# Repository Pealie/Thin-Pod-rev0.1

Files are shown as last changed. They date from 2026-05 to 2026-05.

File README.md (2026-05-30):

# Thin-Pod rev 0.1

<p align="left">
  <a href="https://certification.oshwa.org/uk000091.html">
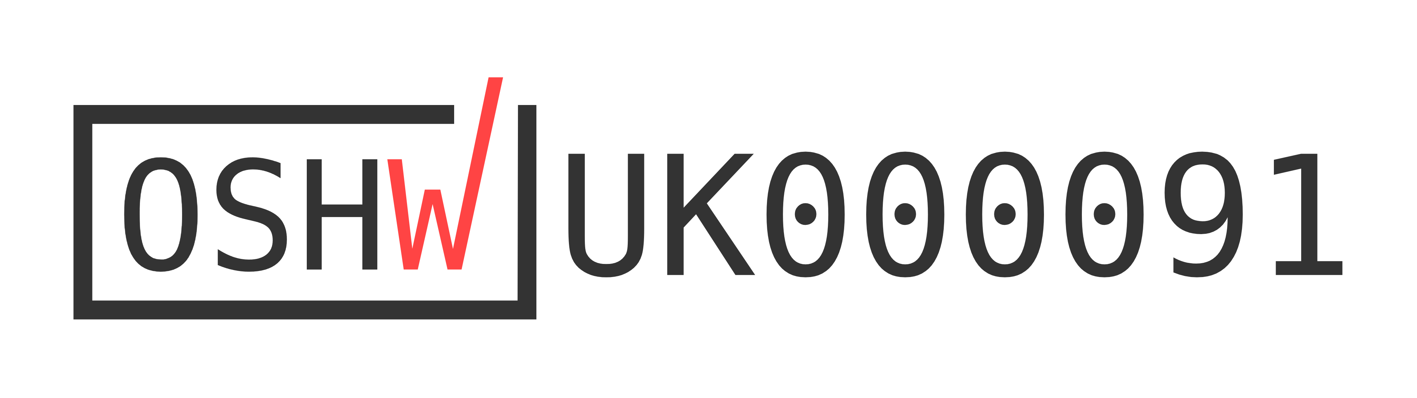
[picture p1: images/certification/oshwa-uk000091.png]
Open Source Hardware Association certification mark: UK000091
    
  </a>
</p>
<p align="left">
  <strong>OSHWA Certified Open Source Hardware · UK000091</strong><br>
  Certified 28 May 2026 · <a href="https://certification.oshwa.org/uk000091.html">View certification record</a>
</p>

## Overview

Thin-Pod rev 0.1 is a compact analogue vibration-sensing carrier board intended for experimental condition-monitoring work on motors, pumps, fans, gearboxes and similar rotating machinery. The board supports an ADXL1005-based analogue accelerometer signal path and provides protected power entry, a regulated and switched sensor supply, signal conditioning, accessible test points and a mating interface for a commercially supplied Qorvo DWM3001-CDK development board.

The design is published as an open-hardware PCB release: editable KiCad source files, project-local library files, fabrication outputs, bill of materials and verification documentation are provided in this repository.

The release is intentionally bounded: its value lies in producing a reproducible, inspectable measurement endpoint whose power path, signal path, interface assumptions and validation evidence can support later Gateway-side analysis, reporting and evaluation work within a clearly defined certified hardware boundary.

## Certification scope

The OSHWA certification for **Thin-Pod rev 0.1** covers the creator-designed sensor-node carrier PCB and its release documentation.

### Included in scope

* Two-layer Thin-Pod carrier PCB design.
* Protected power-entry path, fuse provision and reverse-polarity protection.
* Regulated 3.3 V power path and PFET-switched accelerometer supply.
* ADXL1005 analogue sensor interface and conditioned signal path.
* Electrical test points for bring-up and measurement.
* Thin-Pod-authored mating interface for a Qorvo DWM3001-CDK.
* Corrected carrier-board ground return for the DWM3001-CDK interface.
* Editable KiCad source files, fabrication outputs, BOM and documentation.

### Outside scope

* The Qorvo DWM3001-CDK itself as open hardware.
* The Analog Devices ADXL1005 device or any vendor evaluation board as open hardware.
* The Pololu S7V8F3 regulator module as open hardware.
* The separately developed Thin-Pod Gateway.
* STM32 NUCLEO-N657X0-Q, ESP32-C6 or Gateway-side hardware.
* Implemented UWB communication, radio firmware or networking.
* Gateway-side DSP, TinyML inference, anomaly detection or predictive-maintenance classification.
* AI-assisted maintenance reporting, structured evidence-bound reports or autonomous maintenance decisions.

The commercial devices used by the board are identified as third-party components; they are not relicensed or represented as creator-designed open hardware.

## System role and infrastructure context

Thin-Pod rev 0.1 is the sensing-node hardware layer within a broader experimental condition-monitoring architecture. Its immediate role is to provide a reproducible, inspectable and electrically verified vibration-measurement endpoint for motors, pumps, fans, gearboxes and similar rotating machinery.

```
Machine / motor / pump
        ↓
Thin-Pod rev 0.1 sensing node
        ↓
ADC / UWB-capable commercial module interface
        ↓
Gateway transport and analysis layer
        ↓
Maintenance telemetry / diagnostic workflow
```

The infrastructure concerns addressed by this release are measurement integrity, power-path robustness, interface definition, third-party component boundaries, traceable validation evidence and manufacturable open-hardware documentation.

Only the Thin-Pod rev 0.1 sensing-node carrier PCB and its release documentation are included in the certified open-hardware scope. The ADC-capable commercial module interface is documented as part of the board design, but the commercial module itself is not claimed as open hardware.

Gateway transport, UWB communications, networking, DSP, TinyML, anomaly detection and maintenance-diagnostic workflows are shown here to clarify the intended system context. They are part of the wider Thin-Pod development direction, but remain outside the certified rev 0.1 hardware release.

This boundary is deliberate. Thin-Pod rev 0.1 is designed to make the physical measurement layer explicit before higher-level interpretation is attempted. Later Gateway or software layers can consume the resulting signal path, but any DSP, anomaly detection, AI-assisted reporting or maintenance recommendation must remain separately implemented, evaluated and documented.

## Functional architecture

```text
Mechanical vibration
        ↓
ADXL1005 analogue accelerometer interface
        ↓
Analogue conditioning / filtered signal node
        ↓
Accessible test point and CDK ADC interface
        ↓
Commercial Qorvo DWM3001-CDK connection
```

Power is arranged as:

```text
RAW_IN → fuse provision → 1N5817 reverse-polarity protection
       → Pololu S7V8F3 regulated 3.3 V rail
       → PFET-switched accelerometer supply
```

## Evidence-chain design intent

Thin-Pod rev 0.1 is intended to support an evidence-chain approach to experimental condition monitoring. The carrier board provides the physical sensing and interface layer; later Gateway-side work may attach acquisition metadata, operating-context records, DSP feature outputs, baseline comparisons and report provenance.

In that wider architecture, the hardware layer should remain distinct from any interpretive software layer. The board records or exposes a vibration signal; it does not itself diagnose machine faults. This separation is important for reproducibility, safety, evaluation and possible future AI-assisted reporting workflows.

## DWM3001-CDK ground-return correction

During bring-up of an earlier pre-release manufactured prototype, the CDK did not establish the assumed functional ground return through the original power-entry arrangement alone. A temporary ground jumper allowed successful electrical bring-up and measurement of the sensor path.

Before freezing the rev 0.1 open-hardware release, the CDK mating interface and carrier-board connection were corrected so that all relevant CDK ground connections resolve directly to the Thin-Pod `GND` net:

```text
J1_2    GND    ─┐
J1_6    GND_1  ─┤
J10_9   GND_2  ─┤
J10_14  GND_3  ─┼── GND
J10_20  GND_4  ─┤
J10_25  GND_5  ─┘
```

The editable source and fabrication outputs in this repository include that correction. The temporary jumper is part of the prototype history and is **not** an assembly requirement for the released rev 0.1 design.

## Validation status

The first manufactured pre-release prototype established that the core sensor-node approach is electrically viable. Measurements made during prototype bring-up included:

|Validation item|Result|Evidence status|
|-|-|-|
|Manufactured PCB inspection and initial assembly|Completed|Documented in bring-up record and images|
|Power-up after temporary CDK ground-return correction|Successful|Documented prototype result|
|Switched accelerometer supply rail|Approximately 3.35 V measured|Documented prototype result|
|Filtered analogue sensor output|Approximately 1.76 V measured at rest|Documented prototype result|
|Mechanical excitation / tap response|Visible on oscilloscope|Documented prototype result|
|Ground-return correction implemented in released KiCad source and Gerbers|Completed|Included in this release|
|Physical re-test of the corrected copper implementation without jumper|To be recorded after manufacture of the corrected release board|Not claimed as completed|

The prototype measurement evidence supports the power and analogue signal-chain design. The corrected ground-return implementation is present in the released design files; it is not represented as physically re-tested until a board manufactured from these release Gerbers has been assembled and measured.

## Repository contents

```text
Thin-Pod-rev0.1/
├── README.md
├── LICENCE-HARDWARE.md
├── LICENCE-DOCUMENTATION.md
│
├── hardware/
│   ├── source/
│   │   ├── Thin-Pod_rev0.1.kicad_pro
│   │   ├── Thin-Pod_rev0.1.kicad_sch
│   │   ├── Thin-Pod_rev0.1.kicad_pcb
│   │   ├── fp-lib-table
│   │   ├── sym-lib-table
│   │   ├── footprints/
│   │   │   └── ThinPod.pretty/
│   │   │       └── ThinPod_DWM3001CDK_Mating_Interface_revA.kicad_mod
│   │   └── symbols/
│   │       └── ThinPod.kicad_sym
│   │
│   ├── fabrication/
│   │   ├── gerbers/
│   │   ├── drills/
│   │   └── Thin-Pod_rev0.1_fabrication_outputs.zip
│   │
│   └── bom/
│       ├── Thin-Pod_rev0.1_BOM.md
│       └── Thin-Pod_rev0.1_BOM.csv
│
├── docs/
│   ├── certification-scope.md
│   ├── third-party-components.md
│   ├── footprint-provenance.md
│   ├── prototype-bring-up-and-release-correction.md
│   ├── design-verification.md
│   └── future-revisions.md
│
├── images/
│   ├── certification/
│   │   └── oshwa-uk000091.png
│   ├── prototype-bring-up/
│   ├── gerber-inspection/
│   └── released-design/
│	└── README.md
│
└── oshwa/
    └── application-record.md
    └── README.md
```

## Design and fabrication files

|Resource|Location|Purpose|
|-|-|-|
|Editable KiCad project, schematic and PCB|[`hardware/source/`](hardware/source/)|Preferred source for modification|
|Project-local footprints and symbols|[`hardware/source/`](hardware/source/)|Portable project dependencies|
|Gerber and drill files|[`hardware/fabrication/`](hardware/fabrication/)|PCB fabrication outputs|
|Bill of materials|[`hardware/bom/`](hardware/bom/)|Assembly and sourcing record|
|Certification and design documentation|[`docs/`](docs/)|Scope, provenance and validation record|
|OSHWA application and certification record|[`oshwa/application-record.md`](oshwa/application-record.md)|Public submission details and certification UID|

The editable KiCad source files are the normative design source. Gerbers and drill files are derived fabrication outputs supplied for convenience and reproducibility.

## Bill of materials

The release BOM covers the Thin-Pod rev 0.1 sensor-node carrier board only. It identifies the fitted PCB components, commercial subassemblies, component values, footprints and sourcing information required to reproduce this release.

The Gateway, Gateway-side radio components, ESP32 networking hardware and analytic processing hardware are not part of this BOM because they are outside the rev 0.1 certification scope.

See:

* [`hardware/bom/Thin-Pod_rev0.1_BOM.md`](hardware/bom/Thin-Pod_rev0.1_BOM.md)
* [`hardware/bom/Thin-Pod_rev0.1_BOM.csv`](hardware/bom/Thin-Pod_rev0.1_BOM.csv)

## Third-party components

Thin-Pod rev 0.1 is an open carrier-board design built around commercially available components. The following items are used or interfaced by the design but are not claimed as open-hardware contributions of this project:

|Component|Function in Thin-Pod rev 0.1|Treatment in this release|
|-|-|-|
|Analog Devices ADXL1005-based accelerometer implementation|Analogue vibration sensing|Commercial third-party component; interface documented|
|Qorvo DWM3001-CDK|Commercial module connected through the pod-side mating interface|Commercial third-party development board; not relicensed|
|Pololu S7V8F3|Regulated 3.3 V supply module|Commercial third-party module|
|ZVP2106A and standard passive/protection components|Power switching and analogue support circuitry|Commercial bought-in components identified in BOM|

Vendor documentation is referenced for sourcing and interface understanding; vendor CAD files, proprietary board layouts and vendor 3D models are not distributed under the Thin-Pod hardware licence.

## CDK mating-interface footprint provenance

The published footprint:

```text
hardware/source/footprints/ThinPod.pretty/
└── ThinPod_DWM3001CDK_Mating_Interface_revA.kicad_mod
```

is a Thin-Pod project-local mating-interface footprint for the commercially supplied DWM3001-CDK. It is intended to describe only the mechanical and electrical connection required by the Thin-Pod carrier PCB.

The release footprint was independently constructed in KiCad using standard connector geometry, publicly available interface information and mechanical verification against a purchased CDK unit. It does not distribute a Qorvo-supplied CAD footprint, CDK PCB design or vendor 3D model.

## Opening and modifying the design

The source design is maintained in KiCad 10.0.1. The project is intended to be portable through project-local symbol and footprint tables.

A reproducible modification workflow is:

1. Open `hardware/source/Thin-Pod_rev0.1.kicad_pro` in KiCad 10.0.1 or a compatible later version.
2. Confirm that project-local symbol and footprint libraries resolve through `sym-lib-table` and `fp-lib-table`.
3. Run schematic ERC and PCB DRC before fabrication.
4. Regenerate Gerber and drill outputs after any accepted design change.
5. Inspect copper, solder mask, silkscreen, board outline and drill alignment in KiCad Gerber Viewer before ordering.

## Documentation and verification record

|Document|Content|
|-|-|
|[`docs/certification-scope.md`](docs/certification-scope.md)|Formal inclusion and exclusion boundary for certification|
|[`docs/third-party-components.md`](docs/third-party-components.md)|Commercial component and vendor-material notice|
|[`docs/footprint-provenance.md`](docs/footprint-provenance.md)|Origin and verification of the CDK mating-interface footprint|
|[`docs/prototype-bring-up-and-release-correction.md`](docs/prototype-bring-up-and-release-correction.md)|Prototype test result and ground-return design correction|
|[`docs/design-verification.md`](docs/design-verification.md)|Electrical and fabrication verification record|
|[`docs/future-revisions.md`](docs/future-revisions.md)|Items explicitly outside this release|

## Licensing

|Material|Licence|File|
|-|-|-|
|Creator-designed hardware source, including schematics, PCB layout and Thin-Pod-authored footprint files|CERN Open Hardware Licence Version 2 — Weakly Reciprocal (`CERN-OHL-W-2.0`)|[`LICENCE-HARDWARE.md`](LICENCE-HARDWARE.md)|
|Creator-authored documentation, diagrams and photographs|Creative Commons Attribution 4.0 International (`CC-BY-4.0`)|[`LICENCE-DOCUMENTATION.md`](LICENCE-DOCUMENTATION.md)|
|Software / firmware|None required or supplied for the certified rev 0.1 hardware scope|Not applicable|

Commercial components, vendor documentation and any third-party intellectual property remain subject to their respective owners' terms and are not covered by the Thin-Pod licences. The OSHWA certification mark is used to identify this certified release and is not relicensed as Thin-Pod documentation.

## OSHWA certification record

**Thin-Pod rev 0.1 is certified open source hardware under OSHWA UID UK000091.** The certification mark displayed near the top of this README identifies this specific certified release and links to the public OSHWA record.

|Field|Value|
|-|-|
|Project name|Thin-Pod|
|Project version|0.1|
|Primary project type|Electronics|
|Certification scope|Vibration-sensor node carrier PCB|
|Certification date|28 May 2026|
|Hardware licence|CERN-OHL-W-2.0|
|Documentation licence|CC-BY-4.0|
|Software licence|No software required or supplied for the certified hardware scope|
|OSHWA UID|UK000091|
|Official record|[certification.oshwa.org/uk000091](https://certification.oshwa.org/uk000091.html)|

The certification UID and matching mark are retained in this README and in [`oshwa/application-record.md`](oshwa/application-record.md), keeping the boundary of the certified rev 0.1 release explicit.

## Safety and regulatory note

Thin-Pod rev 0.1 is experimental sensing hardware. It has not been certified for installation on safety-critical machinery, hazardous environments or regulated industrial monitoring applications. Appropriate isolation, current-limited bench testing, secure mechanical mounting and safe working practices are required during evaluation.

This open-hardware release does not imply EMC, radio, electrical-safety or product-regulatory approval. Any commercially supplied radio or development module remains subject to its own vendor documentation and applicable regulatory conditions.

## References

* [Thin-Pod OSHWA Certification Record — UK000091](https://certification.oshwa.org/uk000091.html)
* [OSHWA Certification Mark Usage Guide](https://certification.oshwa.org/mark-usage.html)
* [OSHWA Certification Requirements](https://certification.oshwa.org/requirements.html)
* [OSHWA Certification Documentation Process](https://certification.oshwa.org/process/documentation.html)
* [OSHWA Certification Application](https://application.oshwa.org/apply)
* [Qorvo DWM3001-CDK product page](https://www.qorvo.com/products/p/DWM3001CDK)
* [Analog Devices ADXL1005 product page](https://www.analog.com/en/products/adxl1005.html)

---

**Thin-Pod rev 0.1** is a deliberately bounded first open-hardware release: a documented vibration-sensor node PCB with a clear commercial-module boundary, an independently authored interface footprint, traceable prototype-validation evidence and a release design that incorporates the principal lesson discovered during bring-up.

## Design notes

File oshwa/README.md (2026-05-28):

# OSHWA Certification Record

This directory contains the public certification record for **Thin-Pod rev 0.1**, an open-hardware vibration-sensor node carrier PCB for rotating-machinery experiments.

## Certification status

**Thin-Pod rev 0.1 is OSHWA Certified Open Source Hardware.**

|Field|Value|
|-|-|
|Project|Thin-Pod|
|Hardware release|rev 0.1|
|OSHWA UID|UK000091|
|Certification date|28 May 2026|
|Certified item|Vibration-sensor node carrier PCB|
|Hardware licence|CERN-OHL-W-2.0|
|Documentation licence|CC-BY-4.0|
|Official certification record|[certification.oshwa.org/uk000091](https://certification.oshwa.org/uk000091.html)|

## Contents

|File|Purpose|
|-|-|
|[`application-record.md`](application-record.md)|Public record of the submitted project description, certification boundary, licence declarations, commercial-component treatment, provenance position and verification evidence supporting the certified release.|

## Certified scope

The certification applies to the **Thin-Pod rev 0.1 creator-designed carrier PCB** and its released documentation. The certified hardware scope includes the protected power-entry path, regulated and switched accelerometer supply, ADXL1005-based analogue sensing interface, conditioned signal path, bring-up test points, Thin-Pod-authored DWM3001-CDK mating interface, and the corrected CDK ground-return implementation incorporated in the released design files.

The following remain outside this certification scope:

* commercially supplied components or development boards, including the Qorvo DWM3001-CDK, Analog Devices ADXL1005 device or evaluation hardware, and Pololu S7V8F3 module;
* the separately developed Thin-Pod Gateway;
* implemented UWB communications, radio firmware and networking;
* Gateway DSP, TinyML, anomaly-detection and predictive-maintenance system claims;
* EMC, radio, safety or other regulatory approval.

## Documentation boundary

The open-hardware contribution is the Thin-Pod-created carrier-board design, editable source, fabrication outputs and creator-authored documentation. Bought-in components and third-party CAD dependencies are identified for reproduction and provenance purposes; they are not presented as Thin-Pod-created open hardware or relicensed by this project.

The repository-level description of the certified release is held in [`../README.md`](../README.md). Hardware and documentation licences are provided at:

* [`../LICENCE-HARDWARE.md`](../LICENCE-HARDWARE.md)
* [`../LICENCE-DOCS.md`](../LICENCE-DOCS.md)

## Public-record note

[`application-record.md`](application-record.md) records the public, non-sensitive substance of the OSHWA certification application and subsequent certification milestone. Private postal-address information, private correspondence details and any non-public application data are intentionally excluded.

Any later electrical or mechanical design change should be recorded as a subsequent hardware revision rather than silently replacing the documented **rev 0.1** certified release.

\---

**Thin-Pod rev 0.1 · OSHWA UID UK000091 · Certified 28 May 2026**

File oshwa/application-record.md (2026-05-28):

# Thin-Pod rev 0.1: OSHWA Application Record

**Project:** Thin-Pod  
**Hardware release:** rev 0.1  
**Responsible individual:** Neil Thomson / Pealie  
**Repository:** [Pealie/Thin-Pod-rev0.1](https://github.com/Pealie/Thin-Pod-rev0.1)  
**Application status:** Submitted to the Open Source Hardware Association (OSHWA) certification programme  
**Certification date:** 28 May 2026  
**OSHWA UID:** OSHWA UID UK000091  
**Document status:** Public application record

## 1\. Purpose

This document records the public, non-sensitive substance of the OSHWA certification application submitted for **Thin-Pod rev 0.1**.

The OSHWA application includes private correspondence and address information supplied directly to OSHWA. That information is intentionally not reproduced in this public repository record. This document instead records the certified item, the declared scope, the licensing position, the public documentation location and the supporting design-release evidence.

Once an OSHWA certification UID has been supplied or confirmed in the public certification directory, this document and the repository `README.md` should be updated to include it.

## 2\. Submitted certified item

The item submitted for OSHWA certification is:

> \*\*Thin-Pod rev 0.1: an open-hardware vibration-sensor node carrier PCB for rotating-machinery experiments.\*\*

Thin-Pod rev 0.1 is a creator-designed sensor-node carrier PCB providing protected power entry, regulated and switched sensor power, an ADXL1005-based analogue vibration-sensing interface, signal conditioning, accessible electrical test points and a corrected mating interface for a commercially supplied Qorvo DWM3001-CDK development board.

## 3\. Certification boundary

### Included in the submitted hardware scope

|Included element|Description|
|-|-|
|Thin-Pod rev 0.1 PCB|Two-layer creator-designed sensor-node carrier board|
|Power entry and protection|RAW\_IN connection, fuse provision and 1N5817 reverse-polarity protection|
|Regulated power path|Interface for the specified commercial 3.3 V regulator module|
|Switched sensor supply|PFET-controlled accelerometer supply rail|
|Analogue sensing interface|ADXL1005-based vibration-sensor electrical/mechanical interface|
|Signal conditioning and measurement|Raw/filtered signal path and TP1–TP7 bring-up points|
|CDK carrier interface|Thin-Pod-authored mating-interface footprint and PCB connectivity for the DWM3001-CDK|
|Corrected CDK ground return|Carrier-board ground connection incorporated into the released KiCad source and Gerbers|
|Release source and documentation|Editable KiCad files, fabrication outputs, BOM, provenance record and verification documentation|

### Explicitly outside the submitted scope

|Excluded element|Reason for exclusion|
|-|-|
|Qorvo DWM3001-CDK as open hardware|Commercial third-party development board used by the assembly, not a Thin-Pod-authored product|
|Analog Devices ADXL1005 device or evaluation board as open hardware|Commercial third-party sensing component/module|
|Pololu S7V8F3 module as open hardware|Commercial third-party regulator module|
|Thin-Pod Gateway|Separate evolving hardware artefact|
|STM32 NUCLEO-N657X0-Q and ESP32-C6 Gateway hardware|Outside the sensor-node carrier-board release|
|Implemented UWB communications|No completed wireless-implementation claim was submitted for rev 0.1|
|DSP, TinyML or anomaly detection|Future/system-level processing functionality outside this hardware application|
|Predictive-maintenance performance|No product-performance or diagnostic-accuracy claim forms part of this certification|
|EMC, radio, safety or other regulatory approval|OSHWA certification does not imply regulatory compliance certification|

## 4\. Project information recorded in the application

|Application field|Submitted public project information|
|-|-|
|Project name|`Thin-Pod`|
|Project version|`0.1`|
|Certifying party|Individual|
|Responsible individual|Neil Thomson|
|Country|United Kingdom|
|Project website|[Thin-Pod-rev0.1 GitHub repository](https://github.com/Pealie/Thin-Pod-rev0.1)|
|Documentation location|[Thin-Pod-rev0.1 GitHub repository](https://github.com/Pealie/Thin-Pod-rev0.1)|
|Primary project type|Electronics|
|Additional project type|Science|
|Incorporates hardware already registered with OSHWA|No previous certified Thin-Pod hardware identified for incorporation|
|Previous Thin-Pod OSHWA-certified versions|None|

Private postal-address and OSHWA-correspondence-email information supplied through the application form is omitted from this public record.

## 5\. Project description

The submitted application describes the release boundary in the following terms:

> Thin-Pod rev 0.1 is an open-hardware vibration-sensor node carrier PCB for rotating-machinery experiments. It provides protected power entry, regulated and switched sensor supply, an ADXL1005 analogue signal path, test points, and a corrected carrier-board interface for a commercially supplied Qorvo DWM3001-CDK. The Gateway, wireless implementation, DSP and TinyML are outside this certification scope.

## 6\. Project keywords

The project is described using the following technical keywords:

```text
vibration sensing, condition monitoring, accelerometer, ADXL1005,
rotating machinery, sensor node, KiCad, PCB, open hardware
```

## 7\. Licensing declarations

### 7.1 Submitted licence selections

|Material category in OSHWA application|Declared licence / position|
|-|-|
|Hardware|CERN Open Hardware Licence Version 2 – Weakly Reciprocal (`CERN-OHL-W-2.0`)|
|Software|No software required or supplied for the certified rev 0.1 hardware scope|
|Documentation|Creative Commons Attribution 4.0 International (`CC-BY-4.0`)|

### 7.2 Licence boundary within the repository

|Repository material|Licence treatment|
|-|-|
|Thin-Pod-created schematic, PCB layout and creator-authored hardware source|CERN-OHL-W-2.0|
|Thin-Pod-authored DWM3001-CDK mating-interface footprint|CERN-OHL-W-2.0|
|Thin-Pod-created documentation, diagrams and creator-owned images|CC-BY-4.0|
|Standalone SnapEDA / SnapMagic-derived footprint dependencies, where published|Retained as third-party Design Files under CC BY-SA 4.0 together with the SnapMagic Design Exception 1.0|
|Official KiCad-library-derived footprint dependencies, where locally distributed|Retained under the KiCad Libraries Licence: CC BY-SA 4.0 with the KiCad library exception|
|Purchased components and vendor product documentation|Identified or referenced for reproduction; not relicensed by Thin-Pod|

## 8\. Commercial component declaration

The submitted design necessarily uses commercially supplied hardware components. Their inclusion in the BOM is required for reproduction of the assembly and does not represent a claim that those commercial items are open hardware.

|Ref. / role|Commercial component|Treatment in the release|
|-|-|-|
|`U2` / sensing interface|Analog Devices ADXL1005-based sensor implementation|Proprietary third-party component/module; interface documented|
|`U4` / regulated supply|Pololu S7V8F3 regulator module|Proprietary third-party module; specified in BOM|
|`U5` / CDK connection|Qorvo DWM3001-CDK development board|Proprietary third-party development board; not relicensed|
|`U3`, `D1`, passives, connector and fuse items|Standard commercially supplied electronic components|Specified in BOM for reproducibility|

The openly licensed contribution is the Thin-Pod-created carrier-board design, associated released source and creator-authored documentation, subject to the separately identified third-party CAD dependency boundary.

## 9\. CAD and footprint provenance position

The application documentation distinguishes creator-authored and third-party CAD material as follows.

|Footprint or dependency|Function|Provenance / release position|
|-|-|-|
|`ThinPod\_DWM3001CDK\_Mating\_Interface\_revA.kicad\_mod`|Qorvo CDK carrier-board mating interface|Independently authored Thin-Pod source, released under CERN-OHL-W-2.0|
|`AnalogDevices\_EVAL-ADXL100xZ\_20p35mm.kicad\_mod`|ADXL1005-based module/interface footprint|SnapEDA / SnapMagic third-party Design File, published only under its applicable recorded terms|
|`Pololu\_S7V8F3\_S7V8x\_Module.kicad\_mod`|Regulator-module footprint|SnapEDA / SnapMagic third-party Design File, published only under its applicable recorded terms|
|`PFET\_ZVP2106A\_GSD\_THT.kicad\_mod` or equivalent U3 footprint dependency|PFET THT footprint|Official KiCad-library dependency or KiCad-library-derived local copy, identified under the KiCad Libraries Licence|

No earlier Qorvo-supplied CDK CAD footprint, proprietary vendor board-layout file or vendor 3D model is presented as Thin-Pod-created hardware source in the OSHWA release.

## 10\. Ground-return prototype finding and release correction

A pre-release manufactured prototype identified that the initially assumed Qorvo DWM3001-CDK ground-return arrangement was inadequate for powered bring-up. A temporary jumper to a known CDK ground reference enabled continued prototype testing and successful observation of the analogue sensing path.

Before the rev 0.1 OSHWA-facing release was frozen or submitted, the design was corrected so that the relevant exposed CDK ground connections are bonded directly to the Thin-Pod carrier-board `GND` net:

```text
J1\_2    GND     ─┐
J10\_6   GND\_1  ─┤
J10\_9   GND\_2  ─┤
J10\_14  GND\_3  ─┼── GND
J10\_20  GND\_4  ─┤
J10\_25  GND\_5  ─┘
```

The released rev 0.1 editable source and fabrication outputs incorporate this correction. The temporary jumper is retained in the documentation as a prototype bring-up finding; it is not an assembly requirement for the released design.

## 11\. Verification evidence submitted through the repository

### 11.1 Prototype evidence

|Evidence item|Recorded result|
|-|-|
|Initial PCB manufacture and assembly|Completed for the pre-release prototype|
|Powered bring-up after temporary CDK ground-return correction|Successful|
|Switched accelerometer supply rail|Approximately 3.35 V measured|
|Filtered analogue sensor/ADC-node output at rest|Approximately 1.76 V measured|
|Mechanical excitation / tap test|Visible response observed on the oscilloscope|

### 11.2 Released design evidence

|Evidence item|Recorded status|
|-|-|
|Corrected CDK ground-return design in editable KiCad source|Incorporated before submission|
|Thin-Pod-authored CDK mating-interface footprint|Included as creator-authored hardware source|
|Gerber and drill outputs generated from corrected release design|Included in the release documentation package|
|Gerber top-silkscreen inspection|Reviewed separately from assembly/fabrication drawing layers; no evident unacceptable top-legend overlap|
|Physical test of a newly fabricated PCB from corrected release Gerbers without jumper|Not claimed as completed unless added by a subsequent dated documentation update|

This distinction is deliberate. The repository records successful prototype signal-path bring-up and documents the corrected released source without claiming a physical retest that has not yet occurred.

## 12\. Public documentation package

The application documentation is supplied through the release repository. Its intended principal files are:

|Documentation item|Repository path|
|-|-|
|Main release description|[`README.md`](../README.md)|
|Hardware licence|[`LICENSE-HARDWARE.md`](../LICENSE-HARDWARE.md)|
|Documentation licence|[`LICENSE-DOCUMENTATION.md`](../LICENSE-DOCUMENTATION.md)|
|Editable KiCad hardware source|[`hardware/source/`](../hardware/source/)|
|Gerber and drill fabrication outputs|[`hardware/fabrication/`](../hardware/fabrication/)|
|Bill of materials|[`hardware/bom/`](../hardware/bom/)|
|Certification scope|[`docs/certification-scope.md`](../docs/certification-scope.md)|
|Third-party component boundary|[`docs/third-party-components.md`](../docs/third-party-components.md)|
|Footprint provenance record|[`docs/footprint-provenance.md`](../docs/footprint-provenance.md)|
|Prototype bring-up and release correction|[`docs/prototype-bring-up-and-release-correction.md`](../docs/prototype-bring-up-and-release-correction.md)|
|Design verification record|[`docs/design-verification.md`](../docs/design-verification.md)|
|Deferred/future revisions|[`docs/future-revisions.md`](../docs/future-revisions.md)|

## 13\. Certification status record

|Milestone|Status|Date / identifier|
|-|-|-|
|Dedicated OSHWA-facing repository established|Completed|May 2026|
|Scope narrowed to Thin-Pod sensor-node carrier PCB|Completed|May 2026|
|CDK footprint provenance boundary established|Completed|May 2026|
|Ground-return correction incorporated into release design|Completed before application submission|May 2026|
|OSHWA certification application submitted|Completed|26 May 2026|
|OSHWA UID received or confirmed in directory|**Issued**| 28 May 2026 / **UK000091**|
|Certification identifier added to README and this record|Pending|Complete after UID confirmation|
|Optional corrected-PCB physical re-verification|Pending / future evidence update|Record only when completed|

## 14\. Post-submission update procedure

When an OSHWA UID is received or the project listing becomes visible in the OSHWA certification directory:

1. Add the UID to the table above.
2. Replace `Pending receipt / public directory confirmation` in the document header with the UID.
3. Update `README.md` with the UID and certification-status wording.
4. Add the OSHWA project-directory link, once available.
5. Apply the OSHWA certification mark or identifier only in accordance with the Certification Mark Licence Agreement and OSHWA branding requirements.
6. Preserve the submitted release source and fabrication outputs as a tagged version of the repository, recommended tag: `v0.1-oshwa-submission`.

Any later PCB electrical or mechanical design change should be assigned a subsequent hardware revision rather than silently replacing the submitted rev 0.1 design record.

## 15\. Public-record privacy note

This document deliberately excludes:

* private postal-address details supplied to OSHWA;
* the OSHWA private correspondence-email address;
* any submission confirmation data not intended for public display.

The OSHWA directory may display the public contact information supplied through the application, in accordance with the application form.

## 16\. References

* OSHWA Certification Application: [https://application.oshwa.org/apply](https://application.oshwa.org/apply)
* OSHWA Certification Requirements: [https://certification.oshwa.org/requirements.html](https://certification.oshwa.org/requirements.html)
* OSHWA Documentation Guidance: [https://certification.oshwa.org/process/documentation.html](https://certification.oshwa.org/process/documentation.html)
* OSHWA Certification Mark Licence Agreement: [https://certification.oshwa.org/license-agreement.html](https://certification.oshwa.org/license-agreement.html)
* Thin-Pod rev 0.1 release repository: [https://github.com/Pealie/Thin-Pod-rev0.1](https://github.com/Pealie/Thin-Pod-rev0.1)
* SnapMagic / SnapEDA Terms of Use: [https://www.snapeda.com/about/terms/](https://www.snapeda.com/about/terms/)
* KiCad Libraries Licence: [https://www.kicad.org/libraries/license/](https://www.kicad.org/libraries/license/)

\---

**Submission record:** Thin-Pod rev 0.1 was submitted to the OSHWA certification programme on 26 May 2026 as a bounded open-hardware vibration-sensor node carrier PCB release. This public record will be updated with the OSHWA UID when it is supplied or publicly confirmed.

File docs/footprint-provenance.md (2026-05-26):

# Thin-Pod rev 0.1: Footprint Provenance and Publication Record

**Project:** Thin-Pod  
**Hardware release:** rev 0.1  
**Repository:** `Pealie/Thin-Pod-rev0.1`  
**Prepared by:** Neil Thomson / Pealie  
**Document status:** Hardware-source provenance record  
**Document date:** 26 May 2026  
**EDA tool:** KiCad 10.0.1

## 1\. Purpose

A public open-hardware repository must allow the released PCB to be opened, modified and fabricated without introducing ambiguity about the ownership or licence status of its source dependencies. This document records the provenance and publication treatment of non-standard footprints used in Thin-Pod rev 0.1.

The key distinction is between:

* a Thin-Pod-authored interface footprint created for the released board;
* third-party CAD footprint files downloaded under their own published licensing terms; and
* vendor-supplied files excluded from release because they are not required or do not have a documented redistribution basis.

## 2\. Published footprint inventory

|Footprint file|Board function|Provenance category|Publication status|Licence treatment|
|-|-|-|-|-|
|`ThinPod\_DWM3001CDK\_Mating\_Interface\_revA.kicad\_mod`|Qorvo DWM3001-CDK mating interface at `U5`|Thin-Pod-authored interface footprint|Publish|CERN-OHL-W-2.0|
|`AnalogDevices\_EVAL-ADXL100xZ\_20p35mm.kicad\_mod`|ADXL1005-based evaluation-board / module interface at `U2`|Downloaded from SnapEDA / SnapMagic design-file library|Publish as required third-party dependency, subject to the recorded terms|CC BY-SA 4.0 + SnapMagic Design Exception 1.0|
|`Pololu\_S7V8F3\_S7V8x\_Module.kicad\_mod`|Pololu regulator-module interface at `U4`|Downloaded from SnapEDA / SnapMagic design-file library|Publish as required third-party dependency, subject to the recorded terms|CC BY-SA 4.0 + SnapMagic Design Exception 1.0|
|`PFET\_ZVP2106A\_GSD\_THT.kicad\_mod`|ZVP2106A THT pin/lead arrangement at `U3` |Copied or adapted from an official KiCad library footprint selected in KiCad 10.0.1|Publish as a KiCad-library-derived dependency with attribution and licence notice retained|KiCad Libraries Licence: CC BY-SA 4.0 with KiCad library exception |

Standard KiCad library footprints used for ordinary passives, protection parts, connectors, mounting holes and test points need not be duplicated in the project-local library unless portability requires it. If copied into the repository, their originating licence and attribution must be preserved.

## 3\. Thin-Pod-authored DWM3001-CDK mating-interface footprint

### 3.1 Released file

```text
hardware/source/footprints/ThinPod.pretty/
└── ThinPod\_DWM3001CDK\_Mating\_Interface\_revA.kicad\_mod
```

### 3.2 Function

The footprint represents the **carrier-board mating interface** required to mount and connect a commercially supplied Qorvo DWM3001-CDK to Thin-Pod. It is not a representation of the CDK’s internal PCB design, radio module layout or vendor-owned design source.

It defines the physical connection points needed by the Thin-Pod carrier board, including the J1 and J10 interface pads and the relevant mechanical support geometry.

### 3.3 Authorship and reconstruction method

The released DWM3001-CDK mating-interface footprint was created for Thin-Pod rather than redistributed from a Qorvo CAD library file. Its construction basis is:

* standard connector geometry where applicable;
* publicly available Qorvo product/interface information;
* physical verification against a commercially purchased DWM3001-CDK; and
* Thin-Pod-specific net and ground-return requirements established during prototype bring-up.

The original Qorvo-supplied CDK footprint used during earlier development is not included in the rev 0.1 OSHWA-facing source package.

### 3.4 Corrected ground-return pads

The released footprint makes the required physical pads available for the corrected carrier-board ground arrangement:

|CDK interface pad|Function in released Thin-Pod design|
|-|-|
|`J1\_2`|Connected to Thin-Pod `GND`|
|`J10\_6`|Connected to Thin-Pod `GND`|
|`J10\_9`|Connected to Thin-Pod `GND`|
|`J10\_14`|Connected to Thin-Pod `GND`|
|`J10\_20`|Connected to Thin-Pod `GND`|
|`J10\_25`|Connected to Thin-Pod `GND`|
|`J10\_15`|Analogue ADC/sensor signal interface, as defined by the schematic|
|`J10\_24`|PFET/control interface, as defined by the schematic|

A footprint supplies pads and mechanical geometry; the electrical bonding of the ground pads is implemented in the schematic/PCB net assignment and copper design.

### 3.5 KiCad file identity and UUIDs

The released footprint is saved in a KiCad 10-compatible `.kicad\_mod` format. Its internal KiCad UUIDs are distinct from the earlier development footprint. UUIDs assist KiCad in tracking pads, graphical elements and text objects; they do not by themselves establish authorship or dimensional accuracy.

Independent authorship rests on the reconstruction method and exclusion of the earlier vendor-supplied CAD file. Dimensional correctness rests on mechanical verification, PCB inspection and eventual assembly fit testing.

## 4\. SnapEDA / SnapMagic-derived footprint dependencies

### 4.1 Applicable published terms

The footprint files for the ADXL1005 evaluation-board/module interface and Pololu regulator-module interface were sourced from the SnapEDA web library, now operated under the SnapMagic name.

SnapMagic’s published Terms of Use define these downloaded CAD files as **Design Files**. The terms state that individual Design Files downloaded from SnapMagic are licensed under **Creative Commons Attribution-ShareAlike 4.0 International (`CC BY-SA 4.0`)** and under **Design Exception 1.0**.

The Design Exception permits SnapMagic Design Files to be combined with other selected circuit elements in a circuit-board design, and permits the resulting combination and manufactured board to be conveyed under terms chosen by the designer. The terms also impose a public-distribution restriction of no more than ten Design Files through any one location without prior written permission.

### 4.2 Third-party folder structure

To make the licence boundary unambiguous, the SnapEDA / SnapMagic files should be stored separately from the Thin-Pod-authored footprint library:

```text
hardware/source/footprints/
├── ThinPod.pretty/
│   └── ThinPod\_DWM3001CDK\_Mating\_Interface\_revA.kicad\_mod
│
└── third-party-snapeda.pretty/
    ├── AnalogDevices\_EVAL-ADXL100xZ\_20p35mm.kicad\_mod
    ├── Pololu\_S7V8F3\_S7V8x\_Module.kicad\_mod
    └── NOTICE.md
```

### 4.3 Attribution and file treatment

The standalone SnapEDA / SnapMagic footprint files are not represented as Thin-Pod-created source. They remain third-party Design Files under their stated licensing treatment. Their inclusion is limited to the source material needed to open, edit and reproduce the released Thin-Pod PCB.

The combined Thin-Pod PCB design may be released under the Thin-Pod hardware licence in reliance on the SnapMagic Design Exception, while this document and the neighbouring notice preserve the origin and treatment of the standalone source dependencies.

### 4.4 Source evidence to retain

Prior to release freeze, retained sufficient provenance evidence for each downloaded footprint:

|Evidence item|Purpose|
|-|-|
|SnapEDA / SnapMagic model-page URL or screenshot|Records public source and associated part identity|
|Original downloaded archive, where retained|Records the file as obtained|
|File hash of published `.kicad\_mod` file|Identifies the precise distributed dependency|
|Copy or dated reference to applicable SnapMagic Terms of Use|Records the terms relied upon at release time|

## 5\. Excluded vendor or unrelated CAD files

The following files are excluded from Thin-Pod rev 0.1 publication:

|File or material|Exclusion reason|
|-|-|
|`MODULE\_DWM3001CDK.kicad\_mod`|Earlier Qorvo-supplied/development CDK footprint; replaced by the independently authored Thin-Pod mating-interface footprint|
|`Qorvo\_DWM3001C\_kicad9\_flip.kicad\_mod`|DWM3001C module footprint not required for this CDK-based rev 0.1 board and not part of the release scope|
|`XCVR\_DWM3001C.kicad\_mod`|DWM3001C-related source not required for the released rev 0.1 carrier PCB|
|Qorvo CDK or DWM3001C vendor 3D models|Not needed to fabricate the board and not distributed without an explicit compatible licence|
|Gateway-module footprints|Outside the Thin-Pod rev 0.1 sensor-node certification scope|

## 6\. Footprint verification record

### 6.1 DWM3001-CDK mating interface

|Verification action|Status|Record|
|-|-|-|
|New project-local footprint name assigned|Completed|`ThinPod\_DWM3001CDK\_Mating\_Interface\_revA.kicad\_mod`|
|KiCad 10-compatible file format repaired/saved|Completed in working file; final project-local saved copy to be retained|KiCad 10.0.1|
|New UUID set distinct from earlier footprint|Observed|Supporting identity evidence only|
|Required CDK ground pads represented|Completed|J1/J10 ground pads included|
|Ground pads assigned to common `GND` in released design|Completed in corrected source/Gerbers|Confirm against final KiCad source before tag|
|Gerbers regenerated from corrected release design|Completed in working release set|Final files to be committed under `hardware/fabrication/`|
|Top silkscreen viewed independently of fabrication layer|Completed|No visible unacceptable legend overlap in inspected view|
|Mechanical fit on newly fabricated corrected release PCB|Pending if no corrected board has yet been manufactured|Must not be claimed as completed until tested|

### 6.2 SnapEDA / SnapMagic dependencies

|Verification action|Status required before submission|
|-|-|
|Confirm the two named local files are the downloaded SnapEDA / SnapMagic files used in the PCB|Required|
|Place them in `third-party-snapeda.pretty/` rather than `ThinPod.pretty/`|Required|
|Add local `NOTICE.md` recording source/licence treatment|Required|
|Confirm total distributed SnapMagic Design Files does not exceed ten|Required|
|Confirm no excluded vendor CAD material remains embedded or published unintentionally|Required|

## 7\. Recommended `NOTICE.md` for the third-party footprint folder

The following notice may be placed at:

```text
hardware/source/footprints/third-party-snapeda.pretty/NOTICE.md
```

```markdown
# Third-Party SnapEDA / SnapMagic Footprints

The following CAD footprint files were downloaded from the SnapEDA / SnapMagic
design-file library and are included because they are required to modify and
reproduce the Thin-Pod rev 0.1 PCB source:

- `AnalogDevices\_EVAL-ADXL100xZ\_20p35mm.kicad\_mod`
- `Pololu\_S7V8F3\_S7V8x\_Module.kicad\_mod`

These standalone files are third-party Design Files and are not claimed as
independently authored Thin-Pod source. SnapMagic's published Terms of Use
license individual downloaded Design Files under Creative Commons
Attribution-ShareAlike 4.0 International together with the SnapMagic Design
Exception 1.0.

The complete Thin-Pod rev 0.1 circuit-board design combines these dependency
files with Thin-Pod-created circuit and PCB design material. The combined
Thin-Pod board design is released under CERN-OHL-W-2.0 in reliance on the
SnapMagic Design Exception 1.0.

This repository distributes two SnapMagic Design Files, below the published
restriction against distributing more than ten Design Files through one
location without prior written permission.

Applicable terms:
- https://www.snapeda.com/about/terms/
- https://creativecommons.org/licenses/by-sa/4.0/
```

## 8\. Release sign-off checklist

* \[ ] `ThinPod\_DWM3001CDK\_Mating\_Interface\_revA.kicad\_mod` is the footprint actually used by the released PCB.
* \[ ] The Qorvo-supplied/development CDK footprint is absent from the public repository.
* \[ ] The two SnapEDA / SnapMagic footprint files are isolated in the third-party folder with their notice.
* \[ ] The PFET footprint provenance is confirmed and documented.
* \[ ] Any copied standard KiCad footprint retains its originating licence/attribution, or remains an external library dependency.
* \[ ] The final Gerbers were generated from the same clean footprint set as the published editable PCB source.
* \[ ] DRC, layer inspection and final source-file opening checks are recorded before submission freeze.

## References

* SnapMagic / SnapEDA, *Website Terms of Use*: [https://www.snapeda.com/about/terms/](https://www.snapeda.com/about/terms/)
* Creative Commons, *CC BY-SA 4.0*: [https://creativecommons.org/licenses/by-sa/4.0/](https://creativecommons.org/licenses/by-sa/4.0/)
* OSHWA, *Certification Requirements*: [https://certification.oshwa.org/requirements.html](https://certification.oshwa.org/requirements.html)
* OSHWA, *Documentation*: [https://certification.oshwa.org/process/documentation.html](https://certification.oshwa.org/process/documentation.html)
* Qorvo, *DWM3001-CDK product page*: [https://www.qorvo.com/products/p/DWM3001CDK](https://www.qorvo.com/products/p/DWM3001CDK)

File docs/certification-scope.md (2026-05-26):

# Thin-Pod rev 0.1: OSHWA Certification Scope

**Project:** Thin-Pod  
**Hardware release:** rev 0.1  
**Repository:** `Pealie/Thin-Pod-rev0.1`  
**Prepared by:** Neil Thomson / Pealie  
**Document status:** Submission documentation  
**Document date:** 26 May 2026  

## 1. Purpose

This document defines the precise hardware, documentation and licensing boundary for the Open Source Hardware Association (OSHWA) self-certification application for **Thin-Pod rev 0.1**.

Thin-Pod rev 0.1 is deliberately presented as a bounded first open-hardware release. It is not a claim that the complete future Thin-Pod monitoring system, Gateway, radio communications path, DSP processing chain or TinyML functionality has been completed or certified.

## 2. Certified item definition

The item submitted for certification is:

> **Thin-Pod rev 0.1: an open-hardware vibration-sensor node carrier PCB for rotating-machinery experiments.**

The board provides a physical and electrical platform for an analogue vibration-sensing path built around an ADXL1005-based accelerometer implementation and an interface to a commercially supplied Qorvo DWM3001-CDK development board. It includes protected power input, regulated and switched sensor power, analogue signal conditioning, test points and the corrected ground-return interface required by the CDK connection.

## 3. Included in the certification scope

The following creator-controlled design contributions form the certified hardware release.

| Scope element | Description | Release material |
|---|---|---|
| Carrier PCB | Two-layer Thin-Pod sensor-node printed circuit board design | Editable KiCad PCB source and fabrication outputs |
| Power-entry path | RAW_IN connector provision, fuse provision and series reverse-polarity protection | Schematic, PCB, BOM and fabrication outputs |
| Regulated supply | 3.3 V supply interface using the specified commercial regulator module | Schematic, PCB and BOM |
| Switched sensor rail | PFET-controlled supply path for the accelerometer section | Schematic, PCB and BOM |
| Sensor interface | Electrical and mechanical interface for an ADXL1005-based analogue accelerometer implementation | Schematic, PCB, BOM and applicable footprint source |
| Analogue signal path | Raw sensor output, filtering / ADC node and accessible measurement points | Schematic, PCB and verification record |
| Test-point provision | TP1–TP7 for power and analogue bring-up measurements | Schematic, PCB and BOM |
| CDK mating interface | Thin-Pod-authored interface footprint and carrier connections for a Qorvo DWM3001-CDK | Project-local footprint source, PCB and BOM |
| Corrected CDK ground return | Carrier-board connection of the relevant J1 and J10 CDK ground pins to the Thin-Pod GND net | Schematic, PCB and released Gerbers |
| Documentation | Scope, component boundary, footprint provenance, bring-up history, verification status and future-revision record | Files under `docs/` |
| Fabrication files | Gerber and drill outputs generated from the rev 0.1 release design | Files under `hardware/fabrication/` |

## 4. Explicitly excluded from the certification scope

The following items are outside the Thin-Pod rev 0.1 certification boundary.

| Excluded item | Reason for exclusion |
|---|---|
| Qorvo DWM3001-CDK as a product | Commercial third-party development board; used by the assembly but not claimed as creator-designed open hardware |
| Analog Devices ADXL1005 device or evaluation board as a product | Commercial third-party sensor/device implementation; used by the assembly but not claimed as creator-designed open hardware |
| Pololu S7V8F3 regulator module as a product | Commercial third-party module; specified in the BOM but not claimed as open hardware |
| Thin-Pod Gateway hardware | Separate evolving board design and future certification candidate |
| STM32 NUCLEO-N657X0-Q | Gateway-related commercial development hardware, not part of this node release |
| ESP32-C6 or other onward-networking hardware | Gateway/networking functionality outside this node release |
| Implemented UWB transmission | No certification claim is made for a completed wireless communications path |
| Gateway-side DSP or TinyML | Analytic functionality outside this hardware release |
| Predictive-maintenance or fault-detection performance | No performance claim forms part of this certified carrier-PCB release |
| Regulatory approvals | OSHWA certification is not EMC, radio, safety or product-compliance approval |

## 5. Open-hardware and third-party component boundary

Thin-Pod rev 0.1 includes commercial components because an open PCB design must identify the actual parts required to reproduce its assembly. Inclusion of a component in the BOM does not imply that the component itself is open hardware or relicensed by the project.

The creator-controlled contribution consists of the Thin-Pod carrier-board circuit, PCB layout, Thin-Pod-authored interface footprint material, fabrication outputs and creator-authored documentation. Commercial modules and components remain subject to their suppliers’ terms.

This treatment follows OSHWA’s Creator Contribution principle: creator-controlled contributions are made open, while third-party proprietary components outside the creator’s control are identified distinctly and supported by publicly accessible vendor information.

## 6. Release design and pre-release prototype distinction

A physically assembled pre-release prototype was used for bring-up of the Thin-Pod concept. During that work, the CDK interface was found to require an explicit ground-return connection. The prototype was successfully tested after adding a temporary ground jumper.

The open-hardware **rev 0.1 release design** incorporates that finding in the source files and fabrication outputs. The released PCB connects the relevant CDK ground pins directly to the Thin-Pod `GND` net:

```text
J1_2    GND    ─┐
J10_6   GND_1  ─┤
J10_9   GND_2  ─┤
J10_14  GND_3  ─┼── GND
J10_20  GND_4  ─┤
J10_25  GND_5  ─┘
```

The temporary wire is therefore part of the development and prototype record; it is not an assembly instruction or BOM item for the released rev 0.1 design.

Because no OSHWA submission had been made and no certification release had been frozen before this correction, inclusion of the corrected ground return in rev 0.1 is a pre-release engineering correction rather than an undocumented change to an already-certified product.

## 7. Software scope

No firmware or software is required or supplied as part of the certified Thin-Pod rev 0.1 carrier-PCB scope.

The board provides an analogue sensor path and a physical/electrical connection for a commercial CDK module. Future firmware enabling sampling, UWB packet transport, Gateway processing or analytics is outside this application and will be documented separately if released.

**OSHWA application software licence selection:** `No software`.

## 8. Release licensing

| Material | Licence | Application to this release |
|---|---|---|
| Thin-Pod-created hardware source | CERN Open Hardware Licence Version 2 – Weakly Reciprocal (`CERN-OHL-W-2.0`) | Creator-designed schematic, PCB and Thin-Pod-authored hardware source |
| Thin-Pod-created documentation, diagrams and images | Creative Commons Attribution 4.0 International (`CC-BY-4.0`) | Repository prose, records and creator-owned imagery |
| Standalone SnapEDA / SnapMagic-derived footprints, where included | CC BY-SA 4.0 with SnapMagic Design Exception 1.0, subject to the applicable SnapMagic Terms of Use | Third-party design files kept distinct from Thin-Pod-authored source |
| Commercial hardware components | Manufacturer terms | Physical components are listed for reproduction, not relicensed |

## 9. Application-ready OSHWA field summary

| OSHWA application field | Proposed entry |
|---|---|
| Project name | `Thin-Pod` |
| Project version | `0.1` |
| Certification on behalf of | Individual |
| Responsible individual | Neil Thomson |
| Primary project type | Electronics |
| Additional project type | Science |
| Hardware licence | CERN-OHL-W-2.0 |
| Software licence | No software |
| Documentation licence | CC-BY-4.0 |
| Documentation URL | Public release URL for this repository after completion and release freeze |
| Incorporates already OSHWA-certified hardware | No |
| Previous certified versions | None |

### Project description for application form

> Thin-Pod rev 0.1 is an open-hardware vibration-sensor node carrier PCB for rotating-machinery experiments. It provides protected power entry, regulated and switched sensor supply, an ADXL1005 analogue signal path, test points, and a corrected carrier-board interface for a commercially supplied Qorvo DWM3001-CDK. The Gateway, wireless implementation, DSP and TinyML are outside this certification scope.

## 10. Public documentation required before submission

The repository is ready to serve as the OSHWA documentation location once the following material is present and checked.

| Required or supporting material | Repository location | Status required before submission |
|---|---|---|
| Editable KiCad project/source | `hardware/source/` | Present, openable and checked |
| Project-local footprint and symbol sources | `hardware/source/` | Present with provenance recorded |
| Gerber and drill outputs | `hardware/fabrication/` | Generated from final corrected rev 0.1 source |
| Revision-specific BOM | `hardware/bom/` | Complete and publicly readable |
| Hardware licence | `LICENSE-HARDWARE.md` | Present |
| Documentation licence | `LICENSE-DOCUMENTATION.md` | Present |
| Scope declaration | `docs/certification-scope.md` | Present |
| Third-party component declaration | `docs/third-party-components.md` | Present |
| Footprint provenance record | `docs/footprint-provenance.md` | Present |
| Prototype and correction record | `docs/prototype-bring-up-and-release-correction.md` | Present |
| Verification status | `docs/design-verification.md` | Present and factually current |
| Application record | `oshwa/application-record.md` | Present before or immediately after submission |

## 11. Submission freeze rule

Immediately before submission:

1. Confirm that all published design files correspond to the corrected rev 0.1 release.
2. Confirm that no unlicensed Qorvo-supplied CAD file or vendor 3D model is included.
3. Confirm that all SnapEDA / SnapMagic-derived files are identified under their applicable terms.
4. Confirm that the BOM matches the source and fabrication output set.
5. Confirm that verification claims do not imply physical retesting of the corrected copper design unless that test has actually occurred.
6. Create a repository tag or GitHub release, recommended tag: `v0.1-oshwa-submission`.
7. Use the frozen public release URL in the OSHWA application.

## References

- OSHWA, *Certification Requirements*: <https://certification.oshwa.org/requirements.html>
- OSHWA, *Documentation*: <https://certification.oshwa.org/process/documentation.html>
- OSHWA, *Certification Application*: <https://application.oshwa.org/apply>
- CERN, *CERN Open Hardware Licence Version 2*: <https://ohwr.org/cern_ohl_w_v2.txt>
- Creative Commons, *Attribution 4.0 International*: <https://creativecommons.org/licenses/by/4.0/>

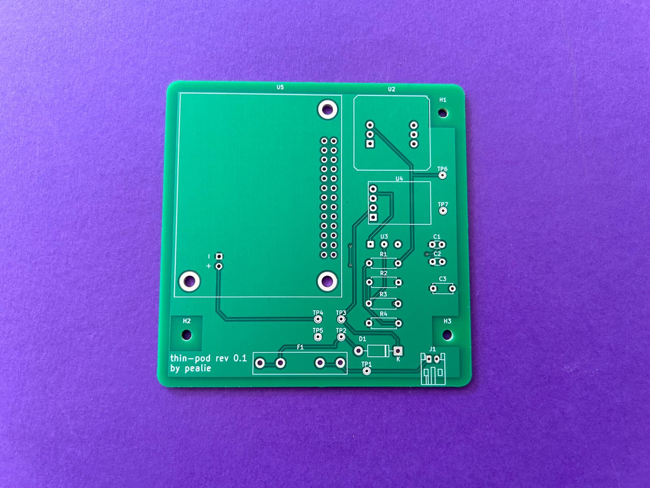
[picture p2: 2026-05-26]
images/thin-pod rev 0.1.jpeg

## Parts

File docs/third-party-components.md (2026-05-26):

# Thin-Pod rev 0.1: Third-Party Components and Licence Boundary

**Project:** Thin-Pod  
**Hardware release:** rev 0.1  
**Repository:** `Pealie/Thin-Pod-rev0.1`  
**Prepared by:** Neil Thomson / Pealie  
**Document status:** Release documentation  
**Document date:** 26 May 2026  

## 1. Purpose

Thin-Pod rev 0.1 is an open-hardware carrier PCB assembled using commercially available electronic parts and development modules. This document distinguishes:

1. Thin-Pod-created design material released as open hardware;
2. proprietary commercial components required to reproduce or use the assembly;
3. third-party CAD/design-file dependencies included under their own licence terms; and
4. vendor materials that are referenced but not redistributed.

A complete BOM must include required proprietary components. Their presence in the BOM is a statement of reproducibility, not a claim that those products have become open source.

## 2. OSHWA component principle

OSHWA requires creator-controlled contributions to be open and calls for best efforts to distinguish proprietary third-party components. OSHWA recognises that open-hardware projects routinely use externally supplied closed components, such as integrated circuits, where those parts are outside the creator’s control and supporting datasheets are accessible and shareable.

Accordingly, Thin-Pod rev 0.1 openly releases its carrier-board design and documentation while identifying commercial components accurately and without attempting to relicense them.

## 3. Thin-Pod-created open-hardware contribution

The following material is intended to be released under **CERN-OHL-W-2.0**:

| Thin-Pod-created material | Description |
|---|---|
| Carrier-board schematic | Electrical design of the rev 0.1 sensor-node PCB |
| Carrier-board PCB layout | Copper, mask, legend, board outline and drilling design |
| Fabrication outputs | Gerbers and drill outputs generated from the released PCB source |
| Thin-Pod-authored CDK mating-interface footprint | Independently produced carrier-board interface representation for the DWM3001-CDK |
| Other project-authored hardware source, where present | Custom material whose provenance is recorded as Thin-Pod-created |

Creator-authored explanatory documents, diagrams and images are licensed separately under **CC-BY-4.0**.

## 4. Commercial components included in the assembly

The principal commercial third-party parts are listed below. They remain products of their respective manufacturers and are not claimed as open-hardware contributions of Thin-Pod.

| Ref. | Component | Manufacturer | Function in Thin-Pod rev 0.1 | Open-hardware status in this release | Public supporting information |
|---|---|---|---|---|---|
| `U2` | ADXL1005-based accelerometer implementation / evaluation-board interface | Analog Devices | Wide-bandwidth analogue vibration sensing | Proprietary third-party sensor or module; not relicensed | ADXL1005 product page and datasheet |
| `U4` | S7V8F3 fixed 3.3 V step-up/step-down regulator module | Pololu | Regulated local power supply | Proprietary third-party module; not relicensed | Pololu product page |
| `U5` | DWM3001-CDK development board | Qorvo | Commercial pod-side MCU/UWB board connected through the carrier interface | Proprietary third-party development board; not relicensed | Qorvo product documentation |
| `U3` | ZVP2106A P-channel MOSFET | Diodes Incorporated | High-side switching of sensor supply rail | Standard proprietary commercial semiconductor; identified in BOM | Manufacturer product information |
| `D1` | 1N5817 Schottky diode | Commercially sourced | Series reverse-polarity protection | Standard proprietary commercial component; identified in BOM | Manufacturer datasheet |
| `J1`, `F1`, `R1–R4`, `C1–C3`, test hardware | Standard interconnect, protection and passive parts | Commercially sourced | Supporting assembly functions | Standard commercial components; identified in BOM | Orderable part information / manufacturer datasheets where applicable |

The precise orderable part numbers and fitted implementation for parts marked for confirmation in the BOM must be completed before the OSHWA submission is frozen.

## 5. U5 / Qorvo DWM3001-CDK treatment

`U5` is correctly included in the BOM because the carrier PCB is designed to interface with it and a functional assembled prototype depends upon that commercial module. The following boundary applies:

| Material | Treatment |
|---|---|
| Qorvo DWM3001-CDK physical development board | Listed in BOM as commercial third-party hardware; not claimed as open |
| Public Qorvo product and interface documentation | Referenced for component identification and interface information |
| Earlier Qorvo-supplied CAD footprint, if held during development | Not distributed in this release repository |
| Thin-Pod CDK mating-interface footprint | Independently authored project file released under CERN-OHL-W-2.0 |
| Thin-Pod PCB copper/net connection to the CDK pads | Creator-designed hardware source released under CERN-OHL-W-2.0 |

The released rev 0.1 design connects the relevant CDK ground pins directly to carrier `GND`, incorporating the ground-return correction discovered in prototype bring-up.

## 6. U2 and U4 footprint files sourced through SnapEDA / SnapMagic

The KiCad footprint files associated with the ADXL1005 evaluation-board interface and the Pololu regulator-module interface were sourced from the SnapEDA library on the web, now presented under the SnapMagic service name.

SnapMagic defines downloaded CAD models, schematics, layouts and related CAD files as **Design Files**. Its published Terms of Use state that individual Design Files downloaded from SnapMagic are licensed under **Creative Commons Attribution-ShareAlike 4.0 International (`CC BY-SA 4.0`)**, together with **Design Exception 1.0**. The Design Exception permits the design, manufacture, use and distribution of circuit-board designs and circuit boards formed by combining SnapMagic Design Files with other chosen circuit elements, and permits those combinations to be conveyed under terms chosen by the designer.

SnapMagic’s terms also state that public files containing Design Files remain subject to the restriction that no more than ten Design Files may be distributed through one location without prior written permission.

### SnapEDA / SnapMagic design-file inventory for this release

| Standalone design file | Used for | Intended repository treatment | Standalone file licence treatment |
|---|---|---|---|
| `AnalogDevices_EVAL-ADXL100xZ_20p35mm.kicad_mod` | `U2` ADXL1005-based evaluation-board / module interface | Include only as required source dependency in a clearly identified third-party library folder | Third-party SnapMagic Design File: CC BY-SA 4.0 + Design Exception 1.0 |
| `Pololu_S7V8F3_S7V8x_Module.kicad_mod` | `U4` regulator-module interface | Include only as required source dependency in a clearly identified third-party library folder | Third-party SnapMagic Design File: CC BY-SA 4.0 + Design Exception 1.0 |

No claim is made that these two standalone files were independently authored by Thin-Pod. They should not be placed inside a folder or licence notice that suggests that they are covered solely as Thin-Pod-created CERN-OHL-W material.

### Recommended directory separation

```text
hardware/source/footprints/
├── ThinPod.pretty/
│   └── ThinPod_DWM3001CDK_Mating_Interface_revA.kicad_mod
│
└── third-party-snapeda.pretty/
    ├── AnalogDevices_EVAL-ADXL100xZ_20p35mm.kicad_mod
    ├── Pololu_S7V8F3_S7V8x_Module.kicad_mod
    └── NOTICE.md
```

The standalone SnapEDA / SnapMagic design files should be accompanied by a local `NOTICE.md` recording the file names, source, applicable terms and the count of SnapMagic Design Files distributed in the repository.

## 7. SnapEDA / SnapMagic distribution count

At the time of preparing this document, the intended published SnapMagic-derived footprint set contains:

| Count | File |
|---:|---|
| 1 | `AnalogDevices_EVAL-ADXL100xZ_20p35mm.kicad_mod` |
| 2 | `Pololu_S7V8F3_S7V8x_Module.kicad_mod` |

**Total SnapMagic Design Files intended for distribution in this repository: 2.**

This remains below the ten-file public-distribution threshold specified in the SnapMagic Terms of Use. If further SnapEDA / SnapMagic files are later included, this table must be revised before public release.

## 8. Files deliberately not distributed

The following material is excluded from the Thin-Pod rev 0.1 repository unless a separate redistribution-compatible licence is subsequently documented:

| Excluded material | Reason |
|---|---|
| `MODULE_DWM3001CDK.kicad_mod` | Earlier Qorvo-supplied/development CDK footprint; replaced by the independently authored Thin-Pod mating-interface footprint |
| `Qorvo_DWM3001C_kicad9_flip.kicad_mod` | DWM3001C module footprint not required for this CDK-based rev 0.1 board and not part of the release scope |
| `XCVR_DWM3001C.kicad_mod` | DWM3001C-related source not required for the released rev 0.1 carrier PCB |
| Qorvo CDK or DWM3001C vendor 3D models | Not needed to fabricate the board and not distributed without an explicit compatible licence |
| Gateway-related hardware source and CAD files | Outside the Thin-Pod rev 0.1 sensor-node certification scope |
| NUCLEO or ESP32-C6 carrier files | Outside the Thin-Pod rev 0.1 sensor-node certification scope |

## 9. Repository licence matrix

| Repository material | Responsible source | Licence / rights statement |
|---|---|---|
| `hardware/source/Thin-Pod_rev0.1.*` and Thin-Pod-authored hardware source | Thin-Pod / Neil Thomson | CERN-OHL-W-2.0 |
| `hardware/fabrication/` outputs generated from the released design | Thin-Pod / Neil Thomson, incorporating declared dependencies | Released with the Thin-Pod hardware design subject to the recorded third-party dependency boundary |
| `docs/`, creator-authored diagrams and creator-owned photographs | Thin-Pod / Neil Thomson | CC-BY-4.0 |
| `ThinPod_DWM3001CDK_Mating_Interface_revA.kicad_mod` | Thin-Pod / Neil Thomson | CERN-OHL-W-2.0 |
| Standalone SnapEDA / SnapMagic footprint files | SnapMagic Design Files / contributing source as applicable | CC BY-SA 4.0 + SnapMagic Design Exception 1.0; retained as third-party source |
| Commercial purchased components and vendor documentation | Respective manufacturers | Referenced only; not relicensed by Thin-Pod |

## 10. Publication checks

Before public OSHWA submission, the release must confirm:

- [ ] The BOM lists all commercial components required to reproduce the assembly.
- [ ] Each commercial module is marked as a third-party proprietary component.
- [ ] No Qorvo-supplied footprint or vendor 3D model is distributed.
- [ ] The Thin-Pod CDK mating-interface footprint is the footprint used by the released PCB.
- [ ] Each SnapEDA / SnapMagic footprint included in the repository has source evidence retained.
- [ ] The SnapMagic Design File count remains at or below ten, unless written permission is obtained.
- [ ] A third-party footprint `NOTICE.md` is present alongside any distributed SnapMagic files.
- [ ] The project licences do not purport to relicense commercial products or standalone third-party files contrary to their own terms.

## References

- OSHWA, *Certification Requirements*: <https://certification.oshwa.org/requirements.html>
- OSHWA, *Documentation*: <https://certification.oshwa.org/process/documentation.html>
- SnapMagic / SnapEDA, *Website Terms of Use*, sections 4 and 5: <https://www.snapeda.com/about/terms/>
- Creative Commons, *CC BY-SA 4.0*: <https://creativecommons.org/licenses/by-sa/4.0/>
- Qorvo, *DWM3001CDK product page*: <https://www.qorvo.com/products/p/DWM3001CDK>
- Analog Devices, *ADXL1005 product page*: <https://www.analog.com/en/products/adxl1005.html>
- Pololu, *3.3 V Step-Up/Step-Down Voltage Regulator S7V8F3*: <https://www.pololu.com/product/2122>

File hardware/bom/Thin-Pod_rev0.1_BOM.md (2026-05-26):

# Thin-Pod rev 0.1 Bill of Materials

**Project:** Thin-Pod  
**Release:** rev 0.1  
**Scope:** OSHWA-facing vibration-sensor node carrier PCB release  
**BOM status:** Release draft derived from the rev 0.1 KiCad source; procurement identifiers marked for confirmation must be completed before public certification submission.

## Scope and release boundary

This BOM covers the corrected **Thin-Pod rev 0.1 sensor-node carrier PCB** only. It includes the commercial sensor, power and Qorvo CDK modules that mate with or are fitted to the carrier board, because those parts are required to reproduce the released hardware assembly.

The following are excluded from this BOM and from the rev 0.1 certification scope:

- Thin-Pod Gateway hardware;
- STM32 NUCLEO-N657X0-Q hardware;
- Gateway-side DWM3001-CDK or DWM3001C hardware;
- ESP32-C6 networking hardware;
- DSP, TinyML, firmware and wireless-system functionality.

The release design incorporates the corrected CDK ground return in PCB copper: `J1_2`, `J10_6`, `J10_9`, `J10_14`, `J10_20` and `J10_25` connect to the carrier-board `GND` net. A temporary ground jumper used during pre-release prototype bring-up is therefore not included as a release BOM item.

## Assembly BOM

| Ref. | Qty | Function | Part / value | Manufacturer / MPN | Footprint | Release note |
|---|---:|---|---|---|---|---|
| `PCB1` | 1 | Thin-Pod carrier printed circuit board | Thin-Pod rev 0.1, 2-layer FR-4 PCB | Fabricator selected by builder | `N/A — PCB fabrication item` | Fabricate from hardware/fabrication outputs; editable source in hardware/source. |
| `J1` | 1 | RAW_IN power entry | JST PH, 2-pin, 2.00 mm pitch, horizontal/side-entry | JST / S2B-PH-K series — confirm exact purchased suffix before public release | `Connector_JST:JST_PH_S2B-PH-K_1x02_P2.00mm_Horizontal` | Matches rev 0.1 KiCad footprint; exact orderable MPN remains to be recorded. |
| `F1 (holder)` | 1 | Input overcurrent protection holder | 5 × 20 mm PCB fuse holder / clip arrangement | Littelfuse-compatible / 445/030 series footprint basis — confirm fitted holder | `Fuse:Fuseholder_Littelfuse_445_030_series_5x20mm` | KiCad design specifies a 5 × 20 mm holder footprint. |
| `F1 (fuse element)` | 1 | Input overcurrent protection | 1 A, 5 × 20 mm cartridge fuse | To be selected / Confirm fuse characteristic and rating before public release | `Installed in F1 holder` | Schematic value is 'Fuse 1A'; slow/fast-blow characteristic is not presently specified. |
| `D1` | 1 | Reverse-polarity series protection | 1N5817 Schottky diode, 20 V, 1 A | Vishay or equivalent / 1N5817 | `Diode_THT:D_DO-41_SOD81_P10.16mm_Horizontal` | Polarity must match RAW_FUSED to RAW_PROT series path. |
| `U4` | 1 | Fixed 3.3 V regulated supply | S7V8F3 step-up/step-down voltage regulator module, 3.3 V fixed | Pololu / 2122 / S7V8F3 | `ThinPod_PowerModules:Pololu_S7V8F3_S7V8x_Module` | Project-local mating/interface footprint must be independently authored or appropriately licensed before publication. |
| `U3` | 1 | PFET high-side switch for accelerometer supply rail | ZVP2106A P-channel enhancement-mode MOSFET | Diodes Incorporated / ZVP2106A | `ThinPod:PFET_ZVP2106A_GSD_THT` | Verify G-S-D mapping against the published footprint before repository release. |
| `U2` | 1 | Analogue vibration sensing | ADXL1005 evaluation-board / breakout implementation | Analog Devices / EVAL-ADXL1005Z — confirm exact physically used assembly before public release | `ThinPod:AnalogDevices_EVAL-ADXL100xZ_20p35mm` | The footprint is a module interface, not a bare ADXL1005BCPZ chip footprint; publish only if independently authored or appropriately licensed. |
| `U5` | 1 | Commercial pod-side MCU/UWB board interface and ADC/control connection | DWM3001CDK Ultra-Wideband Module Development Kit | Qorvo / DWM3001CDK | `ThinPod:ThinPod_DWM3001CDK_Mating_Interface_revA` | Release footprint is Thin-Pod-authored; corrected rev 0.1 interface ties J1_2 and J10_6/9/14/20/25 to carrier GND. |
| `R1` | 1 | Analogue signal series resistor / RC filter element | 8 kΩ | Generic / Any suitable THT axial resistor; 1% recommended | `Resistor_THT:R_Axial_DIN0207_L6.3mm_D2.5mm_P7.62mm_Horizontal` | With C1 = 680 pF, nominal single-pole corner frequency is approximately 29.3 kHz. |
| `R2` | 1 | PFET gate bias resistor | 100 kΩ | Generic / Any suitable THT axial resistor; 1% recommended | `Resistor_THT:R_Axial_DIN0207_L6.3mm_D2.5mm_P7.62mm_Horizontal` | Function and connection should be checked against final corrected schematic. |
| `R3` | 1 | PFET control/gate series resistor | 1 kΩ | Generic / Any suitable THT axial resistor; 1% recommended | `Resistor_THT:R_Axial_DIN0207_L6.3mm_D2.5mm_P7.62mm_Horizontal` | Connected between PFET_CTRL and PFET_GATE in the rev 0.1 design. |
| `R4` | 1 | ADC_NODE pull-down / input reference path | 1 MΩ | Generic / Any suitable THT axial resistor; 1% recommended | `Resistor_THT:R_Axial_DIN0207_L6.3mm_D2.5mm_P7.62mm_Horizontal` | — |
| `C1` | 1 | ADC_NODE RC filter capacitor | 680 pF | Generic / C0G/NP0 ceramic recommended | `Capacitor_THT:C_Disc_D3.0mm_W1.6mm_P2.50mm` | With R1 = 8 kΩ, nominal single-pole corner frequency is approximately 29.3 kHz. |
| `C2` | 1 | Local accelerometer supply decoupling | 100 nF | Generic / Ceramic capacitor; suitable voltage rating | `Capacitor_THT:C_Disc_D3.0mm_W1.6mm_P2.50mm` | — |
| `C3` | 1 | Local accelerometer supply bulk decoupling | 10 µF, non-polar | Generic / Non-polar ceramic or suitable non-polar component; confirm fitted part | `Capacitor_THT:C_Disc_D5.0mm_W2.5mm_P5.00mm` | Rev 0.1 source uses a non-polar THT footprint. |
| `TP1` | 1 | RAW_IN measurement point | RAW_IN | Generic / plated PCB test point | `TestPoint:TestPoint_THTPad_D1.5mm_Drill0.7mm` | — |
| `TP2` | 1 | RAW_FUSED measurement point | RAW_FUSED | Generic / plated PCB test point | `TestPoint:TestPoint_THTPad_D1.5mm_Drill0.7mm` | — |
| `TP3` | 1 | RAW_PROT measurement point | RAW_PROT | Generic / plated PCB test point | `TestPoint:TestPoint_THTPad_D1.5mm_Drill0.7mm` | — |
| `TP4` | 1 | Regulated supply measurement point | 3V3+ | Generic / plated PCB test point | `TestPoint:TestPoint_THTPad_D1.5mm_Drill0.7mm` | — |
| `TP5` | 1 | Ground reference measurement point | GND | Generic / plated PCB test point | `TestPoint:TestPoint_THTPad_D1.5mm_Drill0.7mm` | — |
| `TP6` | 1 | Raw sensor analogue measurement point | SENSOR_SIGNAL_RAW / ACC_VOUT | Generic / plated PCB test point | `TestPoint:TestPoint_THTPad_D1.5mm_Drill0.7mm` | — |
| `TP7` | 1 | Filtered sensor / ADC input measurement point | SENSOR_SIGNAL_FILTERED / ADC_NODE | Generic / plated PCB test point | `TestPoint:TestPoint_THTPad_D1.5mm_Drill0.7mm` | — |

## Proprietary third-party component boundary

The following commercially supplied items are necessary physical components of the released assembly, but are **not** claimed as open-hardware contributions of Thin-Pod:

| Reference | Third-party item | Purpose |
|---|---|---|
| `U2` | Analog Devices ADXL1005 evaluation-board / breakout implementation | Analogue vibration sensing |
| `U4` | Pololu S7V8F3 fixed 3.3 V regulator module | Local regulated supply |
| `U5` | Qorvo DWM3001CDK development board | Pod-side MCU/UWB and ADC/control interface |

The Thin-Pod hardware licence applies to the creator-designed carrier PCB, editable design files and Thin-Pod-authored interface footprints. Commercial components and vendor documentation remain subject to their original manufacturers' terms.

## Footprint and publication notes

| Item | Release treatment |
|---|---|
| `U5` CDK interface | Publish `ThinPod_DWM3001CDK_Mating_Interface_revA.kicad_mod`, the independently authored Thin-Pod mating-interface footprint. Do not publish the earlier Qorvo-supplied `MODULE_DWM3001CDK.kicad_mod`. |
| `U2` ADXL1005 module interface | Confirm that the published interface footprint is independently authored or redistribution-compatible before the repository is made public. |
| `U4` Pololu module interface | Confirm that the published interface footprint is independently authored or redistribution-compatible before the repository is made public. |
| `U3` PFET footprint | Record provenance for the project-local ZVP2106A footprint before public release. |
| Standard KiCad footprints | Retain as standard-library dependencies or preserve their originating licence and attribution if copied into the repository. |

## Board features not separately populated in this BOM

| Reference / feature | Description | Status |
|---|---|---|
| `H1`–`H3` | M2.5 mounting holes, `MountingHole:MountingHole_2.7mm_M2.5` | PCB features; mounting hardware selected according to enclosure/test setup |
| CDK support holes within the U5 interface | Mechanical support provisions included in the mating footprint | PCB features unless spacers/fasteners are specified |
| Copper ground-return correction | CDK J1/J10 ground pins bonded to carrier `GND` in release source and Gerbers | Implemented in PCB copper; no wire-link BOM item |

## Items to confirm before OSHWA submission

The following entries should be closed before the repository is made public and used in the OSHWA application:

1. Confirm the exact orderable JST connector fitted at `J1`.
2. Confirm the fuse element type, breaking characteristic and orderable part number fitted at `F1`.
3. Confirm the precise ADXL1005 evaluation-board or breakout assembly used at `U2`.
4. Confirm independent authorship or redistribution-compatible provenance for the `U2`, `U3` and `U4` project-local footprints.
5. Confirm that the final corrected KiCad schematic and PCB match this BOM and the published fabrication outputs.

## Source basis

The BOM is based on the Thin-Pod rev 0.1 KiCad schematic and PCB source, with the OSHWA release update that replaces the earlier CDK footprint with the independently authored Thin-Pod mating-interface footprint and incorporates the corrected CDK ground return.

Vendor component references:

- Qorvo DWM3001CDK: https://www.qorvo.com/products/p/DWM3001CDK
- Analog Devices ADXL1005: https://www.analog.com/en/products/adxl1005.html
- Pololu S7V8F3: https://www.pololu.com/product/2122
- Diodes Incorporated ZVP2106A: https://www.diodes.com/part/view/ZVP2106A
- Vishay 1N5817 datasheet: https://www.vishay.com/docs/88525/1n5817.pdf

## Licensing

This BOM is documentation for the Thin-Pod rev 0.1 release and is intended to be published under **CC-BY-4.0** together with the project documentation. The creator-designed hardware source files are licensed separately under **CERN-OHL-W-2.0**.

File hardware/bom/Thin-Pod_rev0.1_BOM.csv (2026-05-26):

RefDes | Qty | Category | Function | Value_or_Part | Manufacturer | Manufacturer_Part_Number | Footprint | Population | Third_Party_Status | Datasheet_or_Product_URL | Release_Note
PCB1 | 1 | PCB | Thin-Pod carrier printed circuit board | Thin-Pod rev 0.1, 2-layer FR-4 PCB | Fabricator selected by builder |  | N/A — PCB fabrication item | Required | Thin-Pod-created open-hardware source |  | Fabricate from hardware/fabrication outputs; editable source in hardware/source.
J1 | 1 | Connector | RAW_IN power entry | JST PH, 2-pin, 2.00 mm pitch, horizontal/side-entry | JST | S2B-PH-K series — confirm exact purchased suffix before public release | Connector_JST:JST_PH_S2B-PH-K_1x02_P2.00mm_Horizontal | Required | Commercial component |  | Matches rev 0.1 KiCad footprint; exact orderable MPN remains to be recorded.
F1 (holder) | 1 | Protection | Input overcurrent protection holder | 5 × 20 mm PCB fuse holder / clip arrangement | Littelfuse-compatible | 445/030 series footprint basis — confirm fitted holder | Fuse:Fuseholder_Littelfuse_445_030_series_5x20mm | Required | Commercial component |  | KiCad design specifies a 5 × 20 mm holder footprint.
F1 (fuse element) | 1 | Protection | Input overcurrent protection | 1 A, 5 × 20 mm cartridge fuse | To be selected | Confirm fuse characteristic and rating before public release | Installed in F1 holder | Required | Commercial component |  | Schematic value is 'Fuse 1A'; slow/fast-blow characteristic is not presently specified.
D1 | 1 | Protection | Reverse-polarity series protection | 1N5817 Schottky diode, 20 V, 1 A | Vishay or equivalent | 1N5817 | Diode_THT:D_DO-41_SOD81_P10.16mm_Horizontal | Required | Commercial component | https://www.vishay.com/docs/88525/1n5817.pdf | Polarity must match RAW_FUSED to RAW_PROT series path.
U4 | 1 | Power module | Fixed 3.3 V regulated supply | S7V8F3 step-up/step-down voltage regulator module, 3.3 V fixed | Pololu | 2122 / S7V8F3 | ThinPod_PowerModules:Pololu_S7V8F3_S7V8x_Module | Required | Commercial third-party module; not open hardware | https://www.pololu.com/product/2122 | Project-local mating/interface footprint must be independently authored or appropriately licensed before publication.
U3 | 1 | Power switch | PFET high-side switch for accelerometer supply rail | ZVP2106A P-channel enhancement-mode MOSFET | Diodes Incorporated | ZVP2106A | ThinPod:PFET_ZVP2106A_GSD_THT | Required | Commercial component; Thin-Pod footprint provenance to be recorded | https://www.diodes.com/part/view/ZVP2106A | Verify G-S-D mapping against the published footprint before repository release.
U2 | 1 | Sensor module | Analogue vibration sensing | ADXL1005 evaluation-board / breakout implementation | Analog Devices | EVAL-ADXL1005Z — confirm exact physically used assembly before public release | ThinPod:AnalogDevices_EVAL-ADXL100xZ_20p35mm | Required | Commercial third-party module; not open hardware | https://www.analog.com/en/products/adxl1005.html | The footprint is a module interface, not a bare ADXL1005BCPZ chip footprint; publish only if independently authored or appropriately licensed.
U5 | 1 | UWB development module | Commercial pod-side MCU/UWB board interface and ADC/control connection | DWM3001CDK Ultra-Wideband Module Development Kit | Qorvo | DWM3001CDK | ThinPod:ThinPod_DWM3001CDK_Mating_Interface_revA | Required | Commercial third-party development board; not open hardware | https://www.qorvo.com/products/p/DWM3001CDK | Release footprint is Thin-Pod-authored; corrected rev 0.1 interface ties J1_2 and J10_6/9/14/20/25 to carrier GND.
R1 | 1 | Passive | Analogue signal series resistor / RC filter element | 8 kΩ | Generic | Any suitable THT axial resistor; 1% recommended | Resistor_THT:R_Axial_DIN0207_L6.3mm_D2.5mm_P7.62mm_Horizontal | Required | Standard commercial component |  | With C1 = 680 pF, nominal single-pole corner frequency is approximately 29.3 kHz.
R2 | 1 | Passive | PFET gate bias resistor | 100 kΩ | Generic | Any suitable THT axial resistor; 1% recommended | Resistor_THT:R_Axial_DIN0207_L6.3mm_D2.5mm_P7.62mm_Horizontal | Required | Standard commercial component |  | Function and connection should be checked against final corrected schematic.
R3 | 1 | Passive | PFET control/gate series resistor | 1 kΩ | Generic | Any suitable THT axial resistor; 1% recommended | Resistor_THT:R_Axial_DIN0207_L6.3mm_D2.5mm_P7.62mm_Horizontal | Required | Standard commercial component |  | Connected between PFET_CTRL and PFET_GATE in the rev 0.1 design.
R4 | 1 | Passive | ADC_NODE pull-down / input reference path | 1 MΩ | Generic | Any suitable THT axial resistor; 1% recommended | Resistor_THT:R_Axial_DIN0207_L6.3mm_D2.5mm_P7.62mm_Horizontal | Required | Standard commercial component
C1 | 1 | Passive | ADC_NODE RC filter capacitor | 680 pF | Generic | C0G/NP0 ceramic recommended | Capacitor_THT:C_Disc_D3.0mm_W1.6mm_P2.50mm | Required | Standard commercial component |  | With R1 = 8 kΩ, nominal single-pole corner frequency is approximately 29.3 kHz.
C2 | 1 | Passive | Local accelerometer supply decoupling | 100 nF | Generic | Ceramic capacitor; suitable voltage rating | Capacitor_THT:C_Disc_D3.0mm_W1.6mm_P2.50mm | Required | Standard commercial component
C3 | 1 | Passive | Local accelerometer supply bulk decoupling | 10 µF, non-polar | Generic | Non-polar ceramic or suitable non-polar component; confirm fitted part | Capacitor_THT:C_Disc_D5.0mm_W2.5mm_P5.00mm | Required | Standard commercial component |  | Rev 0.1 source uses a non-polar THT footprint.
TP1 | 1 | Test point | RAW_IN measurement point | RAW_IN | Generic / plated PCB test point |  | TestPoint:TestPoint_THTPad_D1.5mm_Drill0.7mm | PCB pad / optional fitted pin | PCB feature / standard component
TP2 | 1 | Test point | RAW_FUSED measurement point | RAW_FUSED | Generic / plated PCB test point |  | TestPoint:TestPoint_THTPad_D1.5mm_Drill0.7mm | PCB pad / optional fitted pin | PCB feature / standard component
TP3 | 1 | Test point | RAW_PROT measurement point | RAW_PROT | Generic / plated PCB test point |  | TestPoint:TestPoint_THTPad_D1.5mm_Drill0.7mm | PCB pad / optional fitted pin | PCB feature / standard component
TP4 | 1 | Test point | Regulated supply measurement point | 3V3+ | Generic / plated PCB test point |  | TestPoint:TestPoint_THTPad_D1.5mm_Drill0.7mm | PCB pad / optional fitted pin | PCB feature / standard component
TP5 | 1 | Test point | Ground reference measurement point | GND | Generic / plated PCB test point |  | TestPoint:TestPoint_THTPad_D1.5mm_Drill0.7mm | PCB pad / optional fitted pin | PCB feature / standard component
TP6 | 1 | Test point | Raw sensor analogue measurement point | SENSOR_SIGNAL_RAW / ACC_VOUT | Generic / plated PCB test point |  | TestPoint:TestPoint_THTPad_D1.5mm_Drill0.7mm | PCB pad / optional fitted pin | PCB feature / standard component
TP7 | 1 | Test point | Filtered sensor / ADC input measurement point | SENSOR_SIGNAL_FILTERED / ADC_NODE | Generic / plated PCB test point |  | TestPoint:TestPoint_THTPad_D1.5mm_Drill0.7mm | PCB pad / optional fitted pin | PCB feature / standard component

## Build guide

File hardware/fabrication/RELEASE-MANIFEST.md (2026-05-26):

# Thin-Pod rev 0.1 Release Manifest

**Release status:** Submitted for OSHWA self-certification  
**Submission date:** 26 May 2026  
**OSHWA UID:** Pending receipt or public directory confirmation

## Release Identification

|Item|Release record|
|-|-|
|Release|Thin-Pod rev 0.1|
|Submission tag|`v0.1-oshwa-submission`|
|KiCad version|`10.0.1`|
|PCB source file|`Thin-Pod\_rev0.1.kicad\_pcb`|
|Schematic file|`Thin-Pod\_rev0.1.kicad\_sch`|
|Gerber archive|`Thin-Pod\_rev0.1\_fabrication\_outputs.zip`|
|BOM files|`Thin-Pod\_rev0.1\_BOM.md` / `Thin-Pod\_rev0.1\_BOM.csv`|
|CDK footprint|`ThinPod\_DWM3001CDK\_Mating\_Interface\_revA`|
|Ground correction|Included in released copper design|
|Physical evidence|Prototype analogue bring-up validated; corrected release PCB not yet physically re-tested|

## Release Scope

This manifest identifies the fabrication and source-file set associated with the **Thin-Pod rev 0.1** OSHWA certification submission. The released item is the open-hardware vibration-sensor node carrier PCB, including protected power entry, regulated and switched sensor supply, the ADXL1005-based analogue sensing interface, test points and the corrected carrier-board interface for a commercially supplied Qorvo DWM3001-CDK.

The Thin-Pod Gateway, implemented UWB communications, DSP, TinyML and any predictive-maintenance system claim are outside the rev 0.1 certification scope.

## CDK Ground-Return Correction

The released rev 0.1 copper design incorporates the ground-return correction identified during prototype bring-up. The relevant Qorvo DWM3001-CDK interface ground connections are assigned to the Thin-Pod carrier-board `GND` net:

```text
J1\_2    GND    ─┐
J10\_6   GND\_1  ─┤
J10\_9   GND\_2  ─┤
J10\_14  GND\_3  ─┼── GND
J10\_20  GND\_4  ─┤
J10\_25  GND\_5  ─┘
```

A temporary ground jumper was used during bring-up of an earlier pre-release prototype. It is retained as part of the development record, but is not an assembly requirement of the released rev 0.1 PCB.

## Verification Boundary

The pre-release prototype established successful analogue sensor-node proof of life after the temporary ground-return correction, including:

* successful powered bring-up;
* approximately 3.35 V on the switched accelerometer supply rail;
* approximately 1.76 V at the filtered analogue output node at rest; and
* visible response to mechanical excitation on the oscilloscope.

The corrected ground-return arrangement is implemented in the released editable source and Gerber outputs. Physical testing of a PCB manufactured from these corrected release Gerbers, operating without the temporary ground jumper, has not yet been claimed and will be recorded separately when completed.

## Release Files

The following files form the principal source and fabrication record for the submitted release:

```text
hardware/
├── source/
│   ├── Thin-Pod\_rev0.1.kicad\_pro
│   ├── Thin-Pod\_rev0.1.kicad\_sch
│   ├── Thin-Pod\_rev0.1.kicad\_pcb
│   └── footprints/
│       └── ThinPod.pretty/
│           └── ThinPod\_DWM3001CDK\_Mating\_Interface\_revA.kicad\_mod
│
├── fabrication/
│   ├── Thin-Pod\_rev0.1\_fabrication\_outputs.zip
│   └── RELEASE-MANIFEST.md
│
└── bom/
    ├── Thin-Pod\_rev0.1\_BOM.md
    └── Thin-Pod\_rev0.1\_BOM.csv
```

The editable KiCad source files are the normative design source. Gerber and drill files are derived fabrication outputs supplied for manufacture and release reproducibility.

## Associated Documentation

|Document|Purpose|
|-|-|
|`README.md`|Public release landing page and certification summary|
|`docs/certification-scope.md`|Formal certification inclusion and exclusion boundary|
|`docs/third-party-components.md`|Commercial component and licensing boundary|
|`docs/footprint-provenance.md`|Source and licence treatment of non-standard footprints|
|`docs/prototype-bring-up-and-release-correction.md`|Prototype result and incorporated ground-return correction|
|`docs/design-verification.md`|Design and fabrication verification record|
|`docs/future-revisions.md`|Deferred hardware and system scope|
|`oshwa/application-record.md`|Public record of the submitted OSHWA application|

## Future Verification Update

Following manufacture of a board from the corrected rev 0.1 Gerber archive, this manifest may be supplemented with a dated verification update confirming:

1. continuity of the corrected CDK ground connections;
2. correct CDK power-up without the prototype ground jumper;
3. stable regulated and switched supply rails; and
4. repeated analogue vibration response from the released copper implementation.

Any future electrical or mechanical change to the released PCB design should be assigned a subsequent hardware revision rather than silently modifying the submitted rev 0.1 record.

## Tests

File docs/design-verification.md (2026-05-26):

# Thin-Pod rev 0.1: Design Verification Record

**Project:** Thin-Pod  
**Hardware release:** rev 0.1  
**Repository:** `Pealie/Thin-Pod-rev0.1`  
**Prepared by:** Neil Thomson / Pealie  
**Document status:** Release verification record, to be updated as final evidence is committed  
**Document date:** 26 May 2026  
**EDA environment:** KiCad 10.0.1  

## 1. Verification purpose

This document records verification evidence for the Thin-Pod rev 0.1 OSHWA-facing release. It distinguishes evidence established on the initial manufactured prototype from evidence established by inspection of the corrected release design files and evidence still requiring confirmation on a PCB fabricated from the corrected Gerbers.

The certified release claim is appropriately limited: Thin-Pod rev 0.1 is an open-hardware analogue vibration-sensor carrier PCB. It is not a validated end-to-end radio/Gateway/DSP/TinyML product.

## 2. Release hardware summary

Thin-Pod rev 0.1 provides:

- protected RAW_IN power entry;
- fuse provision and 1N5817 reverse-polarity protection;
- a Pololu S7V8F3-based regulated 3.3 V path;
- a PFET-switched accelerometer supply rail;
- an ADXL1005-based analogue vibration-sensor interface;
- raw and filtered analogue signal observation points;
- test points for bring-up;
- a Qorvo DWM3001-CDK mating interface; and
- a corrected CDK ground-return arrangement implemented in the release PCB design.

## 3. Normative release source

The normative source of the rev 0.1 hardware release is the editable KiCad design under `hardware/source/`. Fabrication outputs under `hardware/fabrication/` are derived outputs.

| Source class | Expected file or folder | Verification purpose |
|---|---|---|
| KiCad project | `hardware/source/Thin-Pod_rev0.1.kicad_pro` | Opens the editable design project |
| Schematic | `hardware/source/Thin-Pod_rev0.1.kicad_sch` | Defines circuit/net intent |
| PCB layout | `hardware/source/Thin-Pod_rev0.1.kicad_pcb` | Defines manufacturable board layout |
| Footprint tables | `hardware/source/fp-lib-table` | Resolves project-local footprint libraries |
| Symbol tables | `hardware/source/sym-lib-table` | Resolves project-local symbol libraries |
| Thin-Pod-authored footprint | `hardware/source/footprints/ThinPod.pretty/ThinPod_DWM3001CDK_Mating_Interface_revA.kicad_mod` | Defines published CDK carrier mating interface |
| Third-party footprint dependencies | `hardware/source/footprints/third-party-snapeda.pretty/` | Supplies declared U2/U4 design-file dependencies under their own terms |
| Fabrication outputs | `hardware/fabrication/` | Allows PCB manufacture from the release design |
| BOM | `hardware/bom/` | Identifies assembly components and sourcing boundary |

## 4. Electrical net and test-point intent

### 4.1 Principal power and signal paths

```text
Power entry:
J1 / RAW_IN → F1 → D1 / reverse-polarity protection → U4 regulator → 3V3+

Switched sensor rail:
3V3+ → U3 PFET switch → ACC_3V3_SW → accelerometer supply / local decoupling

Analogue signal path:
ADXL1005-based interface output → SENSOR_SIGNAL_RAW / ACC_VOUT
                               → R1/C1 signal conditioning
                               → SENSOR_SIGNAL_FILTERED / ADC_NODE
                               → CDK interface ADC connection
```

### 4.2 Test-point map

| Test point | Signal / net purpose | Verification use |
|---|---|---|
| `TP1` | `RAW_IN` | Input-supply measurement before protection path |
| `TP2` | `RAW_FUSED` | Post-fuse power-path measurement |
| `TP3` | `RAW_PROT` | Protected input after series diode |
| `TP4` | `3V3+` | Regulated supply measurement |
| `TP5` | `GND` | Measurement reference |
| `TP6` | `SENSOR_SIGNAL_RAW` / sensor raw output as labelled in release source | Analogue sensor observation |
| `TP7` | `SENSOR_SIGNAL_FILTERED` / `ADC_NODE` | Filtered signal / downstream ADC-node observation |

The final labels and net names in the public KiCad files and BOM must agree; any naming refinement should be applied consistently before tagging the OSHWA submission release.

### 4.3 Corrected CDK ground mapping

The released design must show the following CDK physical interface pins connected to the same Thin-Pod `GND` net:

```text
J1_2    GND    ─┐
J10_6   GND_1  ─┤
J10_9   GND_2  ─┤
J10_14  GND_3  ─┼── GND
J10_20  GND_4  ─┤
J10_25  GND_5  ─┘
```

## 5. Prototype physical validation evidence

A pre-release physically manufactured PCB was assembled and tested. During CDK interface bring-up, a missing/insufficient assumed ground-return path was identified and corrected temporarily with a ground jumper. After that correction, the core analogue sensor-node path demonstrated proof of life.

| Verification item | Evidence state | Result |
|---|---|---|
| Physical PCB manufactured and assembled | Completed on pre-release prototype | Board available for bring-up |
| CDK interface ground-return issue identified | Completed on pre-release prototype | Temporary common-ground correction required |
| Powered bring-up after temporary correction | Completed on pre-release prototype | Successful |
| Switched sensor supply rail measurement | Completed on pre-release prototype | Approximately 3.35 V |
| Filtered sensor/ADC-node resting output measurement | Completed on pre-release prototype | Approximately 1.76 V |
| Mechanical excitation observation | Completed on pre-release prototype | Visible tap response on oscilloscope |

### Evidence limitations

This prototype evidence validates the basic power and analogue sensing path after the discovered interface issue was physically corrected. It does not establish:

- completion of a UWB communications path;
- CDK firmware sampling or packet transmission;
- Gateway receipt or memory transfer;
- DSP, TinyML or anomaly-detection results; or
- physical validation of a newly fabricated PCB containing the corrected ground connection in copper.

## 6. Release-design correction verification

The OSHWA-facing rev 0.1 design integrates the ground-return correction before release. The correction must be verified in the published source and outputs.

| Release-design verification check | Status | Evidence / action |
|---|---|---|
| Thin-Pod-authored CDK mating-interface footprint replaces the earlier development/vendor footprint | Completed in working design | Confirm final committed KiCad project references the clean footprint |
| `J1_2` and J10 GND pads are assigned to carrier `GND` | Completed in working design | Confirm schematic and PCB net highlighting before tag |
| Corrected Gerbers generated | Completed in working design | Commit final fabrication-output archive |
| Top silkscreen inspected without confusing `F.Fab` overlay | Completed | Inspected view shows no unacceptable top-silkscreen overlap |
| Gerbers correspond exactly to committed source | Required before tag | Regenerate or verify checksums after final source commit |
| Corrected board fabricated and tested without jumper | Pending unless later completed | Do not claim until measured |

## 7. CAD integrity and provenance verification

| Check | Acceptance criterion | Status before OSHWA submission |
|---|---|---|
| KiCad project opens without missing libraries | All required local tables and files resolve from repository-relative paths | To confirm after final repository population |
| DWM3001-CDK interface footprint provenance | Published footprint is Thin-Pod-authored and earlier Qorvo-supplied footprint is absent | To confirm in final public tree |
| U2/U4 SnapEDA-derived footprint boundary | Files are stored in third-party folder with notice and terms recorded | To confirm in final public tree |
| PFET footprint provenance | Independent authorship or compatible origin recorded | Pending confirmation |
| Schematic ERC | No unresolved errors relevant to released hardware | Run and record final report |
| PCB DRC | No unresolved fabrication/connectivity violations relevant to released hardware | Run and record final report |
| BOM/source consistency | References, values and footprint identities agree across BOM and KiCad design | Confirm before tag |
| Gerber/source consistency | Fabrication archive generated from final committed PCB source | Confirm before tag |

## 8. Gerber and fabrication-output inspection

The release fabrication outputs should be inspected layer-by-layer in KiCad Gerber Viewer before submission and before any fabrication order.

### 8.1 Layer inspection checklist

| Layer / output | Required inspection |
|---|---|
| `F.Cu` | Tracks, pads, pours and corrected CDK ground connectivity appear as intended |
| `B.Cu` | Tracks, pours and via connections appear as intended |
| `F.Mask` | Pad openings and exposed test-point clearances are correct |
| `B.Mask` | Bottom pad/via mask behaviour is correct |
| `F.Silkscreen` | References, polarity marks and board identification are legible and avoid exposed pad openings |
| `B.Silkscreen` | Any bottom legend is intentional and unobstructed |
| `Edge.Cuts` | Closed, correct board outline with intended mounting geometry |
| `PTH drill` | Plated through-holes align with connector and component pads |
| `NPTH drill` | Mechanical and support holes align with intended fit |

### 8.2 Silkscreen inspection record

During Gerber review, apparent text overlaps were initially seen while the front fabrication/assembly drawing layer was displayed. Once `F.Fab` was unselected and the actual front silkscreen was inspected with mask, board outline and drills, the top silkscreen appeared acceptable:

| Inspection point | Finding |
|---|---|
| Component references | Legible in inspected front-silkscreen view |
| Board title / revision marking | Legible |
| Text crossing exposed pad openings | No obvious unacceptable overlap observed |
| D1 polarity/orientation indicator | Visible and useful |
| U5/CDK footprint outline | Clear and uncluttered |
| Earlier apparent text overlap | Located on `F.Fab`, not the manufactured top silkscreen |

Insert retained screenshots in `images/gerber-inspection/` and link them here when committed.

## 9. Corrected release-board physical test plan

The following test sequence is required when a board fabricated from the corrected rev 0.1 Gerbers becomes available.

### 9.1 Unpowered checks

| Check | Expected result | Measured result | Status |
|---|---|---|---|
| Visual inspection of connector orientation and polarity marks | Matches design |  | Pending |
| `GND` continuity to `J1_2` | Continuity |  | Pending |
| `GND` continuity to `J10_6` | Continuity |  | Pending |
| `GND` continuity to `J10_9` | Continuity |  | Pending |
| `GND` continuity to `J10_14` | Continuity |  | Pending |
| `GND` continuity to `J10_20` | Continuity |  | Pending |
| `GND` continuity to `J10_25` | Continuity |  | Pending |
| RAW input / regulated rails to GND | No unintended short |  | Pending |
| Sensor signal node to GND | No unintended short beyond designed paths |  | Pending |

### 9.2 Powered checks

Use a current-limited bench supply and confirm the correct operating supply conditions for each fitted commercial module before power is applied.

| Check | Expected result | Measured result | Status |
|---|---|---|---|
| Correct CDK power-up without temporary ground wire | Normal power behaviour |  | Pending |
| Protected input path | Expected voltage after diode drop |  | Pending |
| Regulated rail | Approximately 3.3 V |  | Pending |
| Switched accelerometer rail | Approximately 3.3 V when enabled |  | Pending |
| Resting filtered sensor signal | Mid-rail analogue value consistent with sensor operation |  | Pending |
| Mechanical excitation response | Observable analogue response at raw/filtered measurement point |  | Pending |
| Abnormal heating | None observed during controlled bring-up |  | Pending |

## 10. Release acceptance statement

At the time this document was prepared, the following statement is defensible:

> The initial Thin-Pod prototype physically demonstrated successful power and analogue vibration-signal bring-up after a temporary ground-return correction at the CDK interface. The OSHWA-facing rev 0.1 release source and Gerbers incorporate that correction in the carrier-board design and publish a clean interface-footprint provenance boundary. Physical testing of a board fabricated from the corrected release Gerbers will be recorded separately when completed and is not claimed prematurely.

## 11. Final sign-off record

Complete this table before tagging the OSHWA submission release.

| Release check | Completed by | Date | Evidence / commit reference |
|---|---|---|---|
| Final KiCad source opens from repository clone |  |  |  |
| Footprint licence/provenance audit complete |  |  |  |
| ERC completed and reviewed |  |  |  |
| DRC completed and reviewed |  |  |  |
| Gerbers regenerated from final committed source |  |  |  |
| Gerber layer inspection complete |  |  |  |
| BOM reconciled to final source |  |  |  |
| Licence files present and correct |  |  |  |
| OSHWA application record prepared |  |  |  |
| Submission tag / release created |  |  |  |

## Related documents

- [`certification-scope.md`](certification-scope.md)
- [`third-party-components.md`](third-party-components.md)
- [`footprint-provenance.md`](footprint-provenance.md)
- [`prototype-bring-up-and-release-correction.md`](prototype-bring-up-and-release-correction.md)
- [`future-revisions.md`](future-revisions.md)

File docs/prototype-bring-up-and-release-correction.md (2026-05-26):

# Thin-Pod rev 0.1: Prototype Bring-Up and Release Correction

**Project:** Thin-Pod  
**Release documented:** rev 0.1  
**Prepared by:** Neil Thomson / Pealie  
**Document status:** Prototype evidence and pre-release design-correction record  
**Document date:** 26 May 2026  

## 1. Purpose

This document records the relationship between:

1. the first physically manufactured Thin-Pod prototype used for electrical bring-up;
2. the ground-return issue found at the Qorvo DWM3001-CDK interface during that work; and
3. the corrected Thin-Pod rev 0.1 design prepared for open-hardware release and OSHWA certification.

The document prevents two opposite errors: concealing a real bring-up issue, or presenting a known and already corrected prototype fault as a permanent requirement of the release design.

## 2. Prototype objective

The first Thin-Pod PCB prototype was created to establish the electrical viability of a compact vibration-sensing carrier board. Its immediate aims were:

- to validate the protected power-entry and regulated supply path;
- to verify the switched accelerometer supply;
- to examine the analogue output and filtered measurement node from an ADXL1005-based sensing section;
- to confirm that an attached Qorvo DWM3001-CDK could form part of the intended pod-side interface; and
- to gather evidence for a release-quality open-hardware design.

The broader Gateway, wireless communications implementation, DSP and TinyML path were not required for this first PCB bring-up.

## 3. Prototype hardware under test

The prototype included the following relevant design blocks:

| Design block | Function |
|---|---|
| RAW_IN power input | External power entry to the carrier board |
| Fuse provision and 1N5817 diode | Basic input protection and reverse-polarity protection |
| Pololu S7V8F3 module | Local regulated 3.3 V supply |
| ZVP2106A PFET circuit | Switched supply control for the sensor section |
| ADXL1005-based sensing interface | Analogue vibration signal production |
| Analogue filtering / ADC node | Conditioned sensor signal for observation and downstream sampling |
| TP1–TP7 | Bring-up and measurement access points |
| Qorvo DWM3001-CDK interface | Commercial CDK connection for intended pod-side processing/radio development |

## 4. Bring-up discovery: CDK ground return

### 4.1 Observed behaviour

During initial testing of the assembled prototype, the intended CDK power/interface arrangement did not provide the expected usable ground-return connection through the assumed path. The attached CDK did not behave as expected until its negative/reference connection was bonded to a confirmed CDK ground point.

### 4.2 Temporary prototype correction

A short temporary ground connection was added between the relevant CDK return point and a known functional CDK ground reference. This was a bring-up correction applied to the physical prototype in order to continue testing the sensor-node electrical path.

The temporary connection served a diagnostic purpose:

- it established a common electrical reference for the attached CDK/interface arrangement;
- it allowed the board to proceed through powered testing; and
- it revealed the required correction for the public release design.

### 4.3 Engineering classification

The finding is treated as a **design-interface error in the pre-release carrier-board implementation**: the interface design relied on a ground-return assumption that proved inadequate in physical bring-up. The outcome is neither concealed nor carried forward as an avoidable assembly workaround.

The appropriate engineering response was to incorporate the necessary ground relationship into the carrier-board release source.

## 5. Prototype measurement evidence after temporary correction

With the temporary ground-return connection in place, prototype testing established proof of life for the essential analogue sensor-node chain.

| Measurement / observation | Prototype result | Interpretation |
|---|---|---|
| Power-up after CDK ground-reference correction | Successful | Prototype could proceed with powered validation once the interface return was established |
| Switched accelerometer supply rail, `/ACC_3V3_SW` | Approximately 3.35 V | Sensor supply path was active and close to the intended 3.3 V rail |
| Filtered sensor output / `SENSOR_SIGNAL_FILTERED` / ADC-node measurement | Approximately 1.76 V at rest | Mid-rail biased analogue output consistent with a 3.3 V-powered analogue accelerometer signal path |
| Gentle tap / mechanical excitation response | Clearly observable on the oscilloscope | The sensor/analogue observation path responded to physical vibration |

These measurements demonstrate the functional promise of the power and analogue signal portions of the prototype. They do not by themselves demonstrate completed wireless sampling, packet transport, Gateway processing or analytic fault detection.

## 6. Release correction incorporated into Thin-Pod rev 0.1

Before the first OSHWA-facing release was frozen or submitted, the CDK carrier interface was corrected in the editable KiCad source and regenerated fabrication outputs.

The released rev 0.1 design connects all relevant exposed CDK ground pins to the Thin-Pod carrier-board `GND` net:

```text
J1_2    GND    ─┐
J10_6   GND_1  ─┤
J10_9   GND_2  ─┤
J10_14  GND_3  ─┼── GND
J10_20  GND_4  ─┤
J10_25  GND_5  ─┘
```

This correction is combined with the project-local, Thin-Pod-authored CDK mating-interface footprint:

```text
ThinPod_DWM3001CDK_Mating_Interface_revA.kicad_mod
```

The new release Gerbers were generated from the corrected design source and are intended to be the fabrication outputs cited by the OSHWA application.

## 7. Versioning position

The corrected ground return is properly part of **Thin-Pod rev 0.1** because:

- the earlier manufactured PCB was a development/prototype bring-up build;
- OSHWA certification had not yet been submitted;
- no frozen public OSHWA release documentation had been issued before correction; and
- the corrected source and Gerbers constitute the first intended open-hardware release definition.

This document preserves the prototype history without requiring builders of the released rev 0.1 design to implement a known unnecessary wire correction.

## 8. What is and is not verified

The evidence must be read precisely.

| Claim | Status |
|---|---|
| A pre-release prototype PCB was fabricated and assembled | Verified |
| The prototype required a temporary CDK ground-reference correction during bring-up | Verified and recorded |
| The power and analogue signal path displayed successful proof-of-life behaviour after the prototype correction | Verified and recorded |
| The released rev 0.1 KiCad source includes the corrected copper/net ground-return design | Implemented in release source; confirm at final tag |
| The released rev 0.1 Gerbers include the corrected ground-return design | Generated and visually inspected in working release set; include in repository |
| A newly manufactured PCB from the corrected release Gerbers has been tested without the temporary wire | Not yet claimed unless subsequently completed and recorded |

## 9. Evidence to include in the repository

The following files or images should be placed in the public release repository where available:

| Evidence item | Suggested location |
|---|---|
| Photographs of the first manufactured prototype PCB | `images/prototype-bring-up/` |
| Photograph of the temporary ground-return correction | `images/prototype-bring-up/` |
| Oscilloscope image showing tap response | `images/prototype-bring-up/` or `images/test-evidence/` |
| Recorded voltage measurement images or log extract | `images/test-evidence/` |
| Screenshot of corrected schematic CDK ground mapping | `images/released-design/` |
| Screenshot of corrected PCB / Gerber interface area | `images/gerber-inspection/` |
| Clean Gerber archive from corrected release design | `hardware/fabrication/` |

## 10. Remaining physical confirmation test for the released correction

A board fabricated from the corrected release Gerbers should be tested using the following focused procedure when available:

1. Visually inspect the new board and confirm correct CDK connector orientation.
2. Use continuity mode, with power removed, to confirm carrier `GND` continuity to `J1_2`, `J10_6`, `J10_9`, `J10_14`, `J10_20` and `J10_25`.
3. Confirm no short exists between the intended supply rail and `GND`.
4. Install the CDK without the prototype ground jumper.
5. Apply current-limited power under the correct supply conditions.
6. Confirm expected CDK power behaviour and stable sensor supply.
7. Repeat the analogue rest-bias and mechanical-excitation observation.
8. Update `docs/design-verification.md` with measured results and dated evidence.

## 11. Conclusion

The first Thin-Pod prototype achieved its central purpose: it revealed both a viable analogue vibration-sensing path and a correctable interface defect. The OSHWA-facing rev 0.1 release incorporates the CDK ground-return lesson into the PCB source and fabrication outputs, leaving the temporary jumper where it belongs: in the documented history of disciplined prototype bring-up rather than in the instructions for the released design.

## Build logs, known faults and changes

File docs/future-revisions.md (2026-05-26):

# Thin-Pod rev 0.1: Future Revisions and Deferred Scope

**Project:** Thin-Pod  
**Current release:** rev 0.1  
**Prepared by:** Neil Thomson / Pealie  
**Document status:** Scope-control and future-work record  
**Document date:** 26 May 2026  

## 1. Purpose

Thin-Pod rev 0.1 is intentionally a bounded first open-hardware release: a vibration-sensor node carrier PCB with a documented analogue measurement path and a corrected commercial-CDK interface.

This document records worthwhile work that is deliberately **not** folded into the rev 0.1 OSHWA certification scope. It prevents future ambitions from obscuring the released hardware claim, while preserving a technically coherent path from an initial verified sensor-node board towards a more complete open condition-monitoring platform.

## 2. Rev 0.1 release boundary

Rev 0.1 is concerned with:

- reproducible open-hardware source for the sensor-node carrier PCB;
- protected and regulated power;
- switched accelerometer supply;
- ADXL1005-based analogue vibration-sensing interface;
- test points and observable raw/filtered signal behaviour;
- commercial Qorvo DWM3001-CDK mating interface;
- corrected CDK ground return in released PCB copper;
- public BOM, fabrication outputs, provenance and verification documentation.

Rev 0.1 is not extended to include a Gateway, radio firmware, analytic model or industrial monitoring claim merely because those elements motivate the longer project.

## 3. Post-release verification without a design-version change

The first outstanding activity after freezing the corrected rev 0.1 release is not necessarily a new design revision. It is physical confirmation of the already released correction.

| Activity | Why it matters | Version treatment |
|---|---|---|
| Fabricate a PCB from the corrected rev 0.1 Gerbers | Confirms the released fabrication package is buildable | Remains rev 0.1 if no design change is introduced |
| Test CDK power/ground behaviour without temporary jumper | Confirms the corrected copper ground return | Verification update to rev 0.1 documentation |
| Repeat sensor rail and analogue tap-response checks | Confirms prototype results on released copper implementation | Verification update to rev 0.1 documentation |
| Add photographs and measurement results | Strengthens OSHWA repository evidence | Documentation update tied to rev 0.1 release |

A new hardware revision is warranted only if the post-release test produces a design change rather than new evidence for the same design.

## 4. Candidate sensor-node rev 0.2 changes

The following improvements belong in a subsequent node revision because they alter or extend the hardware design beyond the rev 0.1 release boundary.

### 4.1 ADXL1005 control-line defaults

The ADXL1005 exposes control functions that should receive explicit design treatment in a future board.

| Signal | Current rev 0.1 treatment | Candidate rev 0.2 treatment | Rationale |
|---|---|---|---|
| `STANDBY` / `STB` | Not fully formalised as a controlled released feature | Add default pulldown to `GND`, likely 100 kΩ, or route to MCU where duty-cycling is required | Establishes a defined default state and supports power-management experiments |
| `ST` / self-test | Not fully formalised as a controlled released feature | Add pulldown to `GND` plus optional test pad or MCU control line | Enables repeatable sensor self-test and removes floating-control ambiguity |

These are particularly suitable for rev 0.2 because they convert prototype learning into explicit measurement-integrity features without altering the central sensor-platform concept.

### 4.2 Layout and manufacturability refinement

| Candidate change | Motivation |
|---|---|
| Move regulator and local passives closer to the sensor supply section where practical | Reduce supply-loop length and improve physical organisation |
| Evaluate more compact component placement | Reduce board area while retaining accessible testability |
| Move selected components to SMT where appropriate | Improve manufacturing readiness and reduce assembly bulk |
| Retain clear test points during miniaturisation | Avoid trading verifiability for compactness |
| Improve silkscreen and fabrication-layer annotation | Make assembly and review cleaner without changing function |
| Formalise enclosure/mounting interface | Prepare the sensing node for repeatable machine attachment |

### 4.3 Sensor implementation decision

Rev 0.1 is based on an ADXL1005-related module/interface arrangement suitable for first hardware proof. A later release should explicitly decide between:

| Direction | Advantages | Considerations |
|---|---|---|
| Continue with a commercial evaluation/breakout implementation | Fast assembly and lower assembly risk | Larger, less product-like and dependent on a third-party module |
| Integrate bare ADXL1005 device onto the custom PCB | Cleaner OSHWA hardware artefact and manufacturing path | LFCSP assembly requirements, layout care and test/assembly risk |

This decision should be made in conjunction with assembly capability and the intended OSHWA/manufacturing-readiness objective.

## 5. Communications-module evolution

Rev 0.1 uses a carrier interface to a **Qorvo DWM3001-CDK** development board. Future designs may move towards the smaller **DWM3001C** castellated module.

| Revision direction | Hardware treatment | Rationale |
|---|---|---|
| Rev 0.1 | CDK-based interface retained | Suitable for prototype/release evidence and accessible development |
| Later node or Gateway revision | Consider DWM3001C module on a custom PCB | Smaller, cleaner module-based integration while retaining Qorvo’s local UWB subsystem |
| Premature chip-down DW3110 integration | Not presently preferred | Increases radio/integration burden and weakens the modular architecture |

The preferred architectural principle is to treat the Qorvo module as a communications subsystem with a stable documented interface, rather than prematurely merging radio-level complexity into the creator-designed sensing or Gateway board.

## 6. Thin-Pod Gateway as a separate product

The Gateway is not part of the Thin-Pod rev 0.1 certification. It should continue as a separate design and, when mature, as a separate OSHWA certification candidate.

### 6.1 Preferred Gateway architecture

The current preferred architecture is modular:

```text
Thin-Pod sensor node
    ↓  UWB vibration-window transport
DWM3001C / DWM3001-CDK subsystem on Gateway side
    ↓  documented host interface
STM32 NUCLEO-N657X0-Q or later custom supervisor platform
    ↓
DSP / feature extraction / TinyML / onward network reporting
```

The Qorvo subsystem should handle UWB communications locally through its nRF52833/DW3110 arrangement, while the NUCLEO-class host acts as analytic supervisor rather than attempting direct low-level control of the radio IC.

### 6.2 Gateway work explicitly deferred

| Deferred work | Reason for exclusion from rev 0.1 |
|---|---|
| Gateway PCB fabrication and verification | Separate hardware artefact |
| DWM3001C module integration on Gateway PCB | Separate interface/layout work |
| NUCLEO host interface proof | Separate communications and firmware milestone |
| ESP32-C6 onward-networking path | Separate networking subsystem |
| PoE supply integration | Gateway power-domain issue, not sensor-node rev 0.1 |
| Gateway OSHWA application | Requires its own frozen source, BOM and verification package |

## 7. Firmware and data-transport path

Firmware is outside the rev 0.1 certification scope, but the future design direction is sufficiently clear to record without claiming completion.

### 7.1 Intended data model

The intended transport model is based on short vibration windows rather than always-on streaming:

```text
Sensor samples a bounded vibration window
        ↓
Window is framed with asset/calibration/processing metadata
        ↓
UWB subsystem transfers the window locally
        ↓
Gateway receives window into analytic memory
        ↓
DSP features and optional TinyML decisions are generated
```

### 7.2 First firmware proof milestones

| Milestone | Description |
|---|---|
| Synthetic buffer path | Demonstrate a known buffer travelling from the Gateway-side Qorvo subsystem into NUCLEO-accessible memory |
| Received vibration-window path | Replace the synthetic buffer with an actual UWB-received sensor window |
| DSP feature proof | Calculate RMS, kurtosis, crest factor, band energy and envelope from a received window |
| Versioned processing record | Record firmware/calibration/processing version metadata alongside results |
| TinyML evaluation | Begin only after the data path and DSP baseline are reproducible |

None of these milestones is claimed by the rev 0.1 hardware certification package.

## 8. Measurement integrity and security posture

Security is not merely an application-layer addition for a sensing system: it affects confidence in the measurement record. From rev 0.2 onward, documentation should begin to formalise:

- sensor identity and calibration state;
- firmware identity and build version;
- packet path and transport integrity;
- Gateway processing version;
- model identity, if TinyML is introduced;
- alert/decision traceability; and
- reproducible comparison between raw windows and derived metrics.

This work belongs in a dedicated security-and-trust document for later system releases, not in a claim that rev 0.1 already implements end-to-end trust.

## 9. Research and evaluation direction

A mature Thin-Pod platform may support publishable engineering investigation, especially where it measures the relationship between signal fidelity, transmission cost and energy use.

A promising future research question is:

> How much fault-relevant vibration information is retained per joule consumed and per byte transmitted as window length, sample rate, feature selection and UWB transport settings vary?

This question is deliberately deferred until the sensor-node hardware, communications path and Gateway data ingestion path have each been made reproducible.

## 10. Candidate revision roadmap

| Stage | Deliverable | Definition of completion |
|---|---|---|
| rev 0.1 | OSHWA-facing sensor-node carrier PCB release | Public editable source, BOM, fabrication files, provenance boundary and certification submission |
| rev 0.1 verification update | Corrected-board physical test evidence | Board fabricated from released Gerbers powers and responds without temporary jumper |
| rev 0.2 | Refined sensor-node hardware | ST/STANDBY treatment, layout/manufacturing refinements and any chosen sensor/module transition |
| Gateway revision | Independently released Gateway hardware | Frozen source/BOM/fabrication documentation and verified host/UWB interface |
| System demonstration | End-to-end vibration-window transfer | Received window arrives at Gateway memory reproducibly |
| Analytic release | DSP baseline and optional TinyML | Versioned processing pipeline with measurable validation evidence |

## 11. Change-control rule

No future feature should be silently folded into the rev 0.1 certification record after submission. Later changes should be handled as follows:

| Change type | Treatment |
|---|---|
| Additional photographs, measurement results or clarification for unchanged rev 0.1 design | Update documentation with dated record |
| Correction of minor typographical/documentation error | Update documentation transparently |
| Electrical, mechanical or PCB-layout design change after rev 0.1 is frozen | Assign a subsequent hardware revision and retain rev 0.1 documentation |
| Addition of Gateway, radio implementation, DSP or TinyML claim | Separate product/system documentation and, where appropriate, separate OSHWA submission |

## 12. Conclusion

Thin-Pod rev 0.1 should remain small, exact and defensible: an open vibration-sensor node PCB with a corrected commercial-CDK interface and a truthful prototype-to-release record. Its value is strengthened, not diminished, by keeping the Gateway, communications system and analytic ambition visible as future work rather than prematurely absorbing them into the first certification boundary.

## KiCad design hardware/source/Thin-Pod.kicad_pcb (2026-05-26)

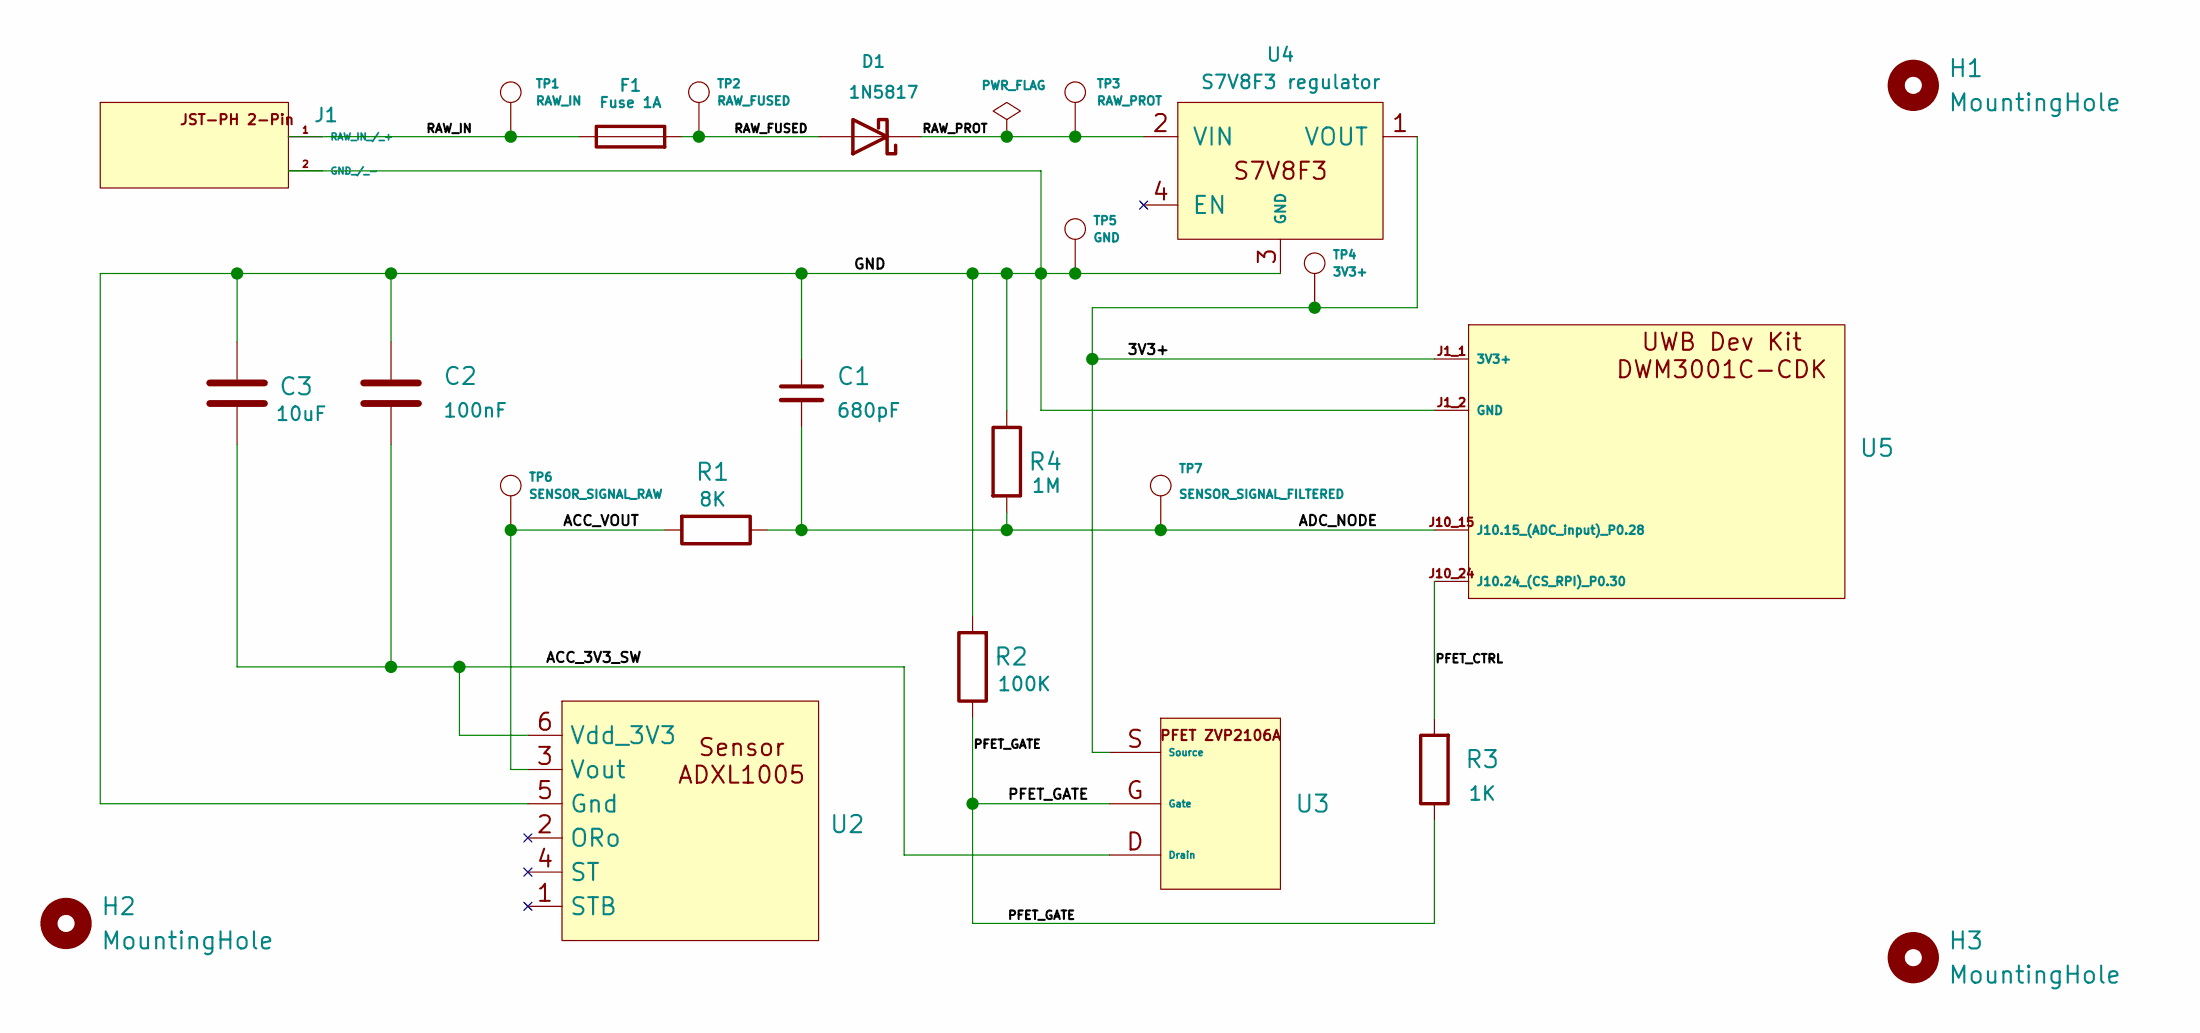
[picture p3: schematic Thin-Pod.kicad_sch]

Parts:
C1: 680pF; C_Disc_D3.0mm_W1.6mm_P2.50mm
C2: 100nF; C_Disc_D3.0mm_W1.6mm_P2.50mm
C3: 10uF; C_Disc_D5.0mm_W2.5mm_P5.00mm
D1: 1N5817; D_DO-41_SOD81_P10.16mm_Horizontal
F1: Fuse 1A; Fuseholder_Littelfuse_445_030_series_5x20mm
H1, H2, H3: MountingHole; MountingHole_2.7mm_M2.5
J1: JST_PH_S2B-PH-K_1x02_P2.00mm_Horizontal
R1: 8K; R_Axial_DIN0207_L6.3mm_D2.5mm_P7.62mm_Horizontal
R2: 100K; R_Axial_DIN0207_L6.3mm_D2.5mm_P7.62mm_Horizontal
R3: 1K; R_Axial_DIN0207_L6.3mm_D2.5mm_P7.62mm_Horizontal
R4: 1M; R_Axial_DIN0207_L6.3mm_D2.5mm_P7.62mm_Horizontal
TP1: RAW_IN; TestPoint_THTPad_D1.5mm_Drill0.7mm
TP2: RAW_FUSED; TestPoint_THTPad_D1.5mm_Drill0.7mm
TP3: RAW_PROT; TestPoint_THTPad_D1.5mm_Drill0.7mm
TP4: 3V3+; TestPoint_THTPad_D1.5mm_Drill0.7mm
TP5: GND; TestPoint_THTPad_D1.5mm_Drill0.7mm
TP6: SENSOR_SIGNAL_RAW; TestPoint_THTPad_D1.5mm_Drill0.7mm
TP7: SENSOR_SIGNAL_FILTERED; TestPoint_THTPad_D1.5mm_Drill0.7mm
U2: AnalogDevices_EVAL-ADXL100xZ_20p35mm
U3: PFET_ZVP2106A_GSD_THT
U4: S7V8F3 regulator; Pololu_S7V8F3_S7V8x_Module
U5: DWM3001C-CDK; MODULE_DWM3001CDK

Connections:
/3V3+: TP4.1 (1_1), U3.S (Source), U4.1 (VOUT), U5.J1_1 (3V3+)
/ACC_3V3_SW: C2.2, C3.2, U2.6 (Vdd_3V3), U3.D (Drain)
/ACC_VOUT: R1.2, TP6.1 (1_1), U2.3 (Vout)
/ADC_NODE: C1.2, R1.1, R4.2, TP7.1 (1_1), U5.J10_15 (J10.15_(ADC_input)_P0.28)
/GND: C1.1, C2.1, C3.1, J1.2 (GND_/_-), R2.2, R4.1, TP5.1 (1_1), U2.5 (Gnd), U4.3 (GND), U5.J1_2 (GND), U5.J10_6, U5.J10_9, U5.J10_14, U5.J10_20, U5.J10_25
/PFET_CTRL: R3.2, U5.J10_24 (J10.24_(CS_RPI)_P0.30)
/PFET_GATE: R2.1, R3.1, U3.G (Gate)
/RAW_FUSED: D1.2 (A), F1.2, TP2.1 (1_1)
/RAW_IN: F1.1, J1.1 (RAW_IN_/_+), TP1.1 (1_1)
/RAW_PROT: D1.1 (K), TP3.1 (1_1), U4.2 (VIN)

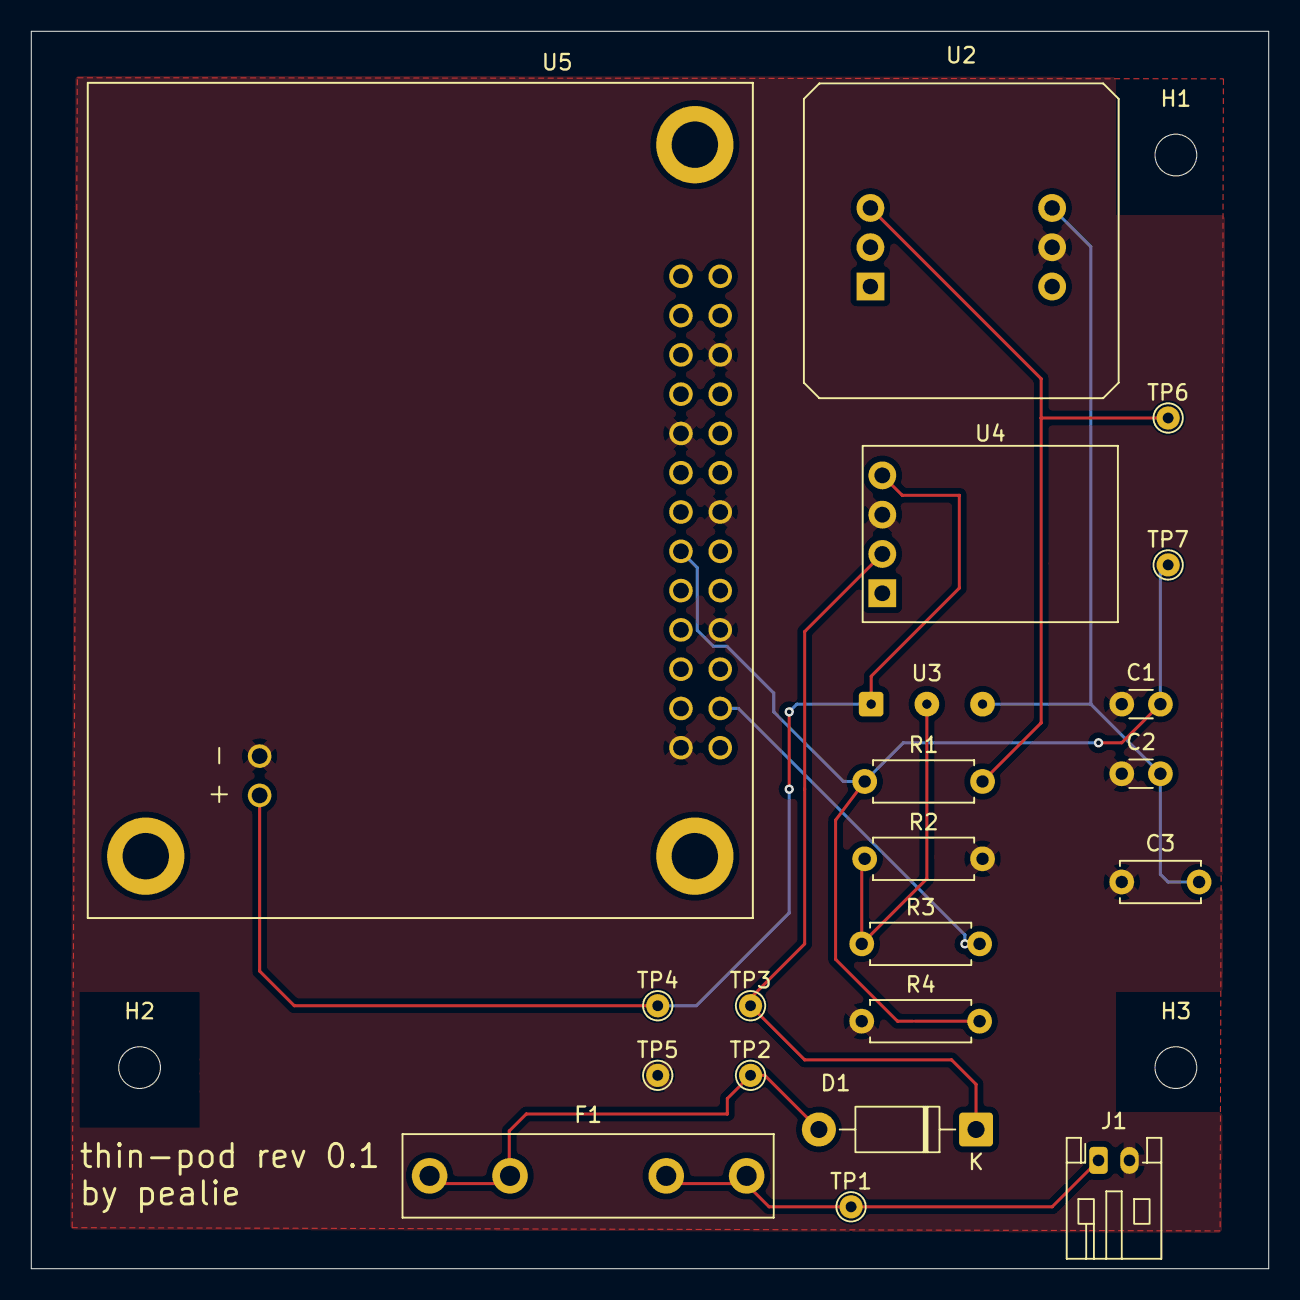
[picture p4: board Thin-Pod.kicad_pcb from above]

Board: 2 copper layers, 80.0 x 80.0 mm, 24 parts (0 on the bottom side), 10 nets.
